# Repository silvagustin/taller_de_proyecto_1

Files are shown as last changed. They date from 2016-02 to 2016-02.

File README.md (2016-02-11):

# Proyecto: Control para una matriz de LEDs

### Palabras clave:
- EDU CIAA-NXP, CIAA, poncho, shield, matriz de leds 8x8, LCD 1602,LCD 16x02, teclado matricial.

### Interfaces:
- LCD 16x02
- Teclado Matricial 4 filas 3 columnas

### Grupo 5, integrantes:
- Buján Ariel,   157/0
- Delgado David, 139/8
- Silva Agustín, 63/5

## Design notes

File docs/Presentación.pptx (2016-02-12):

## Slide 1

Control de una matriz de LEDs de N x N con la EDU-CIAA

157/0 – Buján, Ariel
139/8 – Delgado, David
63/5 – Silva, Agustín

## Introducción

- Se diseñó e implementó un poncho para la placa controladora EDU-CIAA. Dicho poncho sirve para controlar una matriz de leds de 8x8, y cuenta con una interfaz de entrada/salida para comunicarse con el usuario.

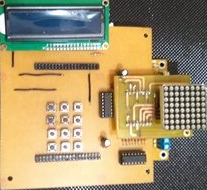
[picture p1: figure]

## Materiales

- 1 Matriz de Leds de 8x8
- 1 Display LCD 16x02
- 1 Demultiplexor CMOS 74HC238 DIP-16
- 1 Demultiplexor CMOS 74HC138 DIP-16
- 2 Tiras de 20 pines macho dobles
- 2 Tiras de 8 pines hembras
- 1 Tira de 16 pines hembras
- 12 Pulsadores touch de 6 mm
- 2 Capacitores cerámicos de 100nF
- 2 Capacitores electrolíticos de 22uF
- 9 Resistencias de 220 ohms
- 1 Preset de 10k ohm
- 1 Placa pcb de cobre

## Funcionamiento del sistema

- El sistema total del poncho puede dividirse en tres grandes subsistemas, que se intercomunican entre sí:

- Control de la Matriz de 8x8
- Display LCD
- Teclado Matricial

## Control de la Matriz de 8x8

- El control de la matriz de leds se realiza mediante dos demultiplexores, uno normal, el cual devuelve una sola salida activa por combinación en las entradas, y uno invertido, que devuelve todas las salidas excepto una encendidas en la salida por combinación en la entrada.
- Los demultiplexores se controlan con ocho puertos GPIO configurados como salidas.
- Tres puertos para controlar la combinación en las entradas del demultiplexor y el cuarto para habilitar o deshabilitar el Enable 1.
- Los pines de las matrices comerciales pueden variar entre los diferentes modelos. Este poncho está pensado para poder ser utilizado con cualquiera de estos modelos, para esto se le añade un sobre-poncho el cual, la única función que cumple es reordenar los pines de forma que un demultiplexor controle las filas y el otro controle las columnas.

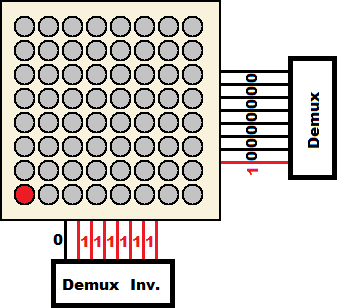
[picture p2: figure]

## Display LCD

- Se utilizaron los pines asignados en el diseño de la EDU-CIAA para controlar el Display, pero, debido a que aún no existe un driver destinado a controlar este componente, se implementó por medio del control de los GPIO, enviando un paquete de bits en paralelo y luego un bit por el puerto RS para indicar si se trataba de un dato o una instrucción.

## Teclado Matricial

- Una vez más se utilizaron los pines asignados por el diseño de la EDU-CIAA pero se implementaron las funciones de control por medio de los GPIO.
- 4 GPIOs definidos como salidas ( para las filas), que sucesivamente cambian de estado de forma que siempre haya uno con valor 0(cero) y el resto con valor 1(uno).
- 3 GPIOs definidos como entradas con PULL-UP (para las columnas).
- De esta forma se puede identificar que pulsador se presionó, conociendo en qué entrada llegó un 0(cero), y que salida tiene ese valor asignado.

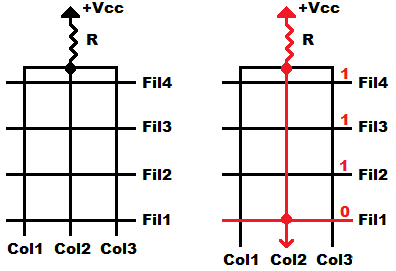
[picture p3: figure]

## Teclado Matricial

- Nota: Cabe destacar que el PULL-UP es una medida de seguridad, ya que sin este, la conexión realizada entre Vcc y GND (el GPIO puesto en 0) resultara en un cortocircuito, al existir una resistencia (programada al definir el GPIO) se limita la corriente que ingresa por los puertos de las columnas, y de este modo no se daña la EDU-CIAA.

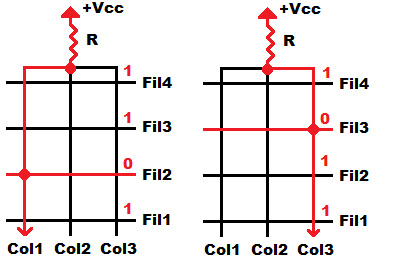
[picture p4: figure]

## Menú de la interfaz

- Menú principal: Luego de encender la placa, aparecerá un mensaje de bienvenida durante algunos segundos, seguido del menú principal que permitirá al usuario moverse entre las funciones básicas del sistema.

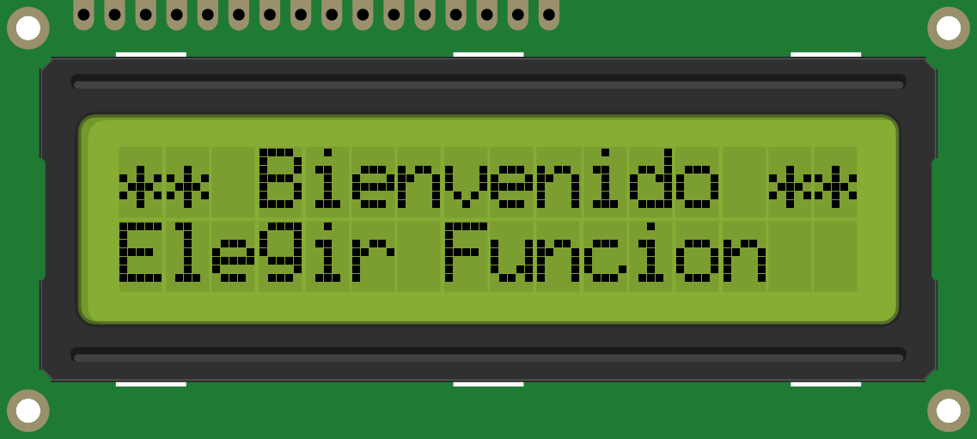
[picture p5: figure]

## Menú Principal

Para moverse por las funciones se utilizan los botones 4 y 6 (las flechitas), al llegar a la ultima función el circulo vuelve a empezar. Para seleccionar una función debe presionarse la tecla OK.
Las funciones son:
  - Escribir Texto
  - Enviar Texto
  - Velocidad Matriz

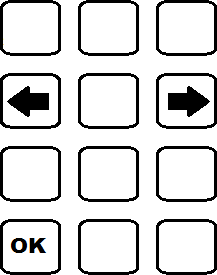
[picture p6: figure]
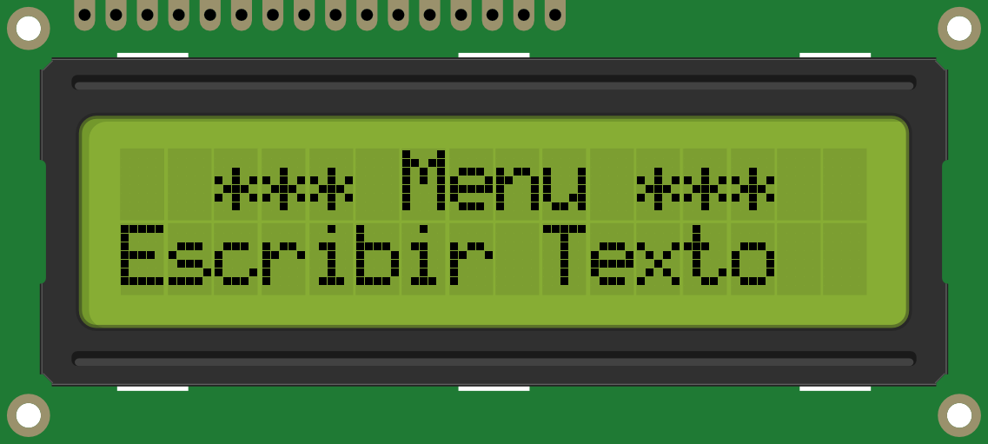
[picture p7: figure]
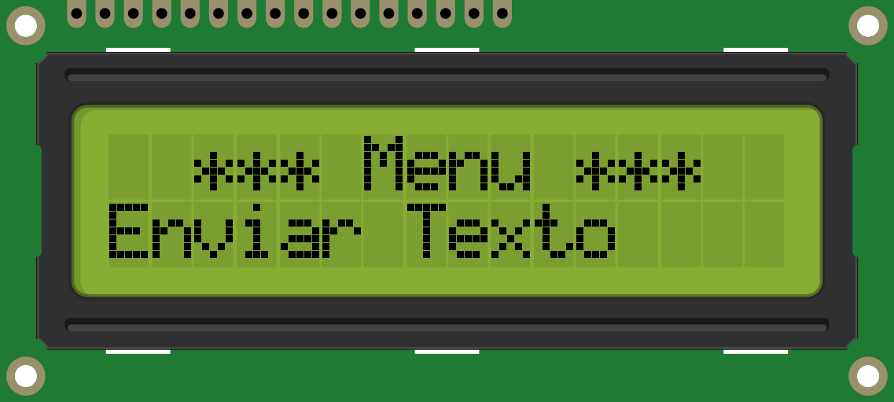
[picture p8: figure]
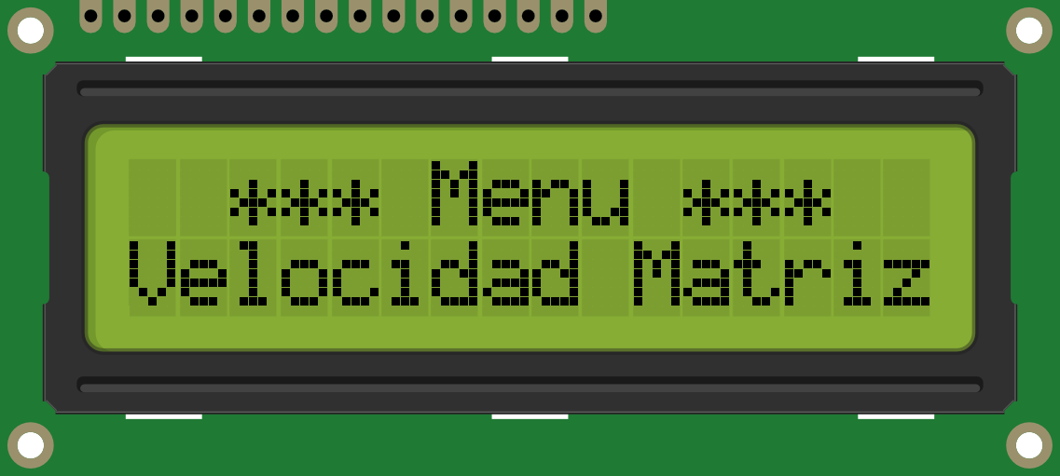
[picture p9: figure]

## Escribir texto

- Permite escribir un texto para ser enviado y mostrado en la matriz de leds, el control es bastante intuitivo. La distribución de teclas está dada de una forma similar a los celulares de la década del 90.

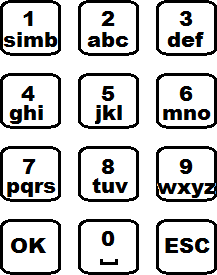
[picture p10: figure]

## Escribir texto – Maquina de Estados

- Modo Escritura: Luego de seleccionar un carácter se debe confirmar el mismo con la tecla OK.
- Modo Borrado: Si se desea borrar un carácter o más, se debe presionar dos veces ESC, de esta forma se ingresa al modo borrado, para continuar borrando se debe volver a presionar ESC. Para volver al modo escritura, se debe presionar OK nuevamente.
- Modo Salida: Para volver al menú principal se debe presionar una vez la tecla ESC y confirmar con OK.

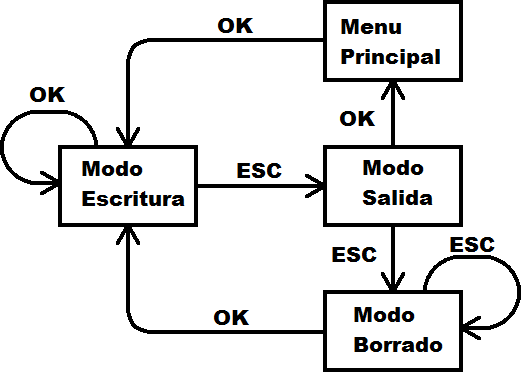
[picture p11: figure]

## De modo escritura a modo borrado pasando por modo salida

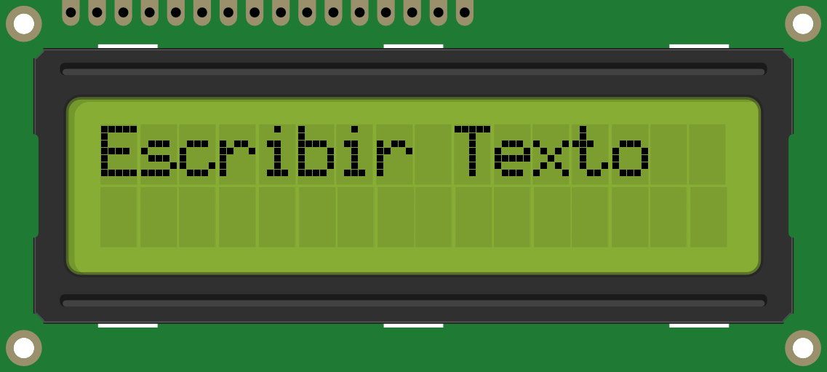
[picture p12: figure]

…

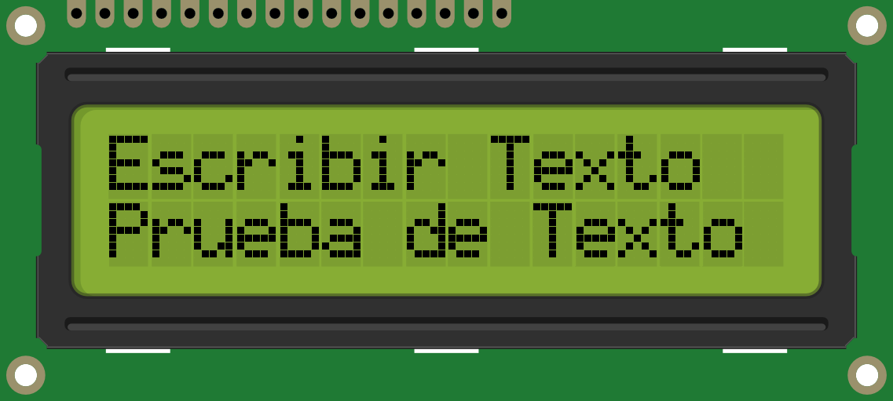
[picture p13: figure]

ESC

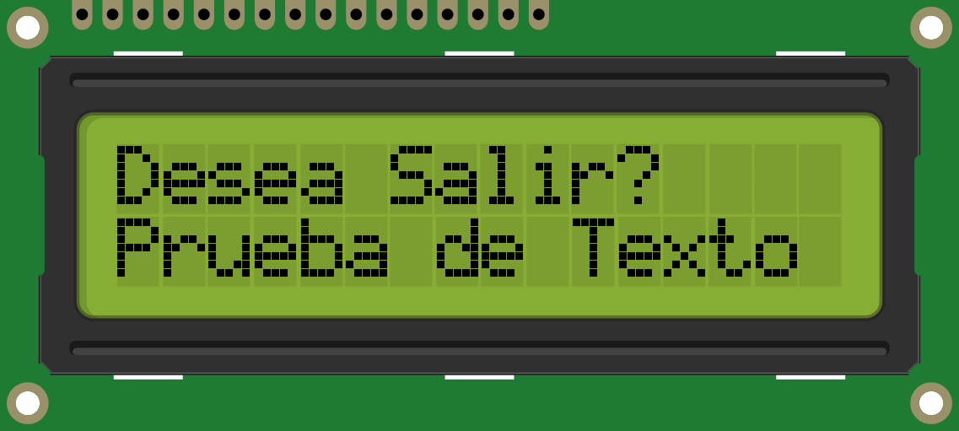
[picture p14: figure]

ESC

ESC

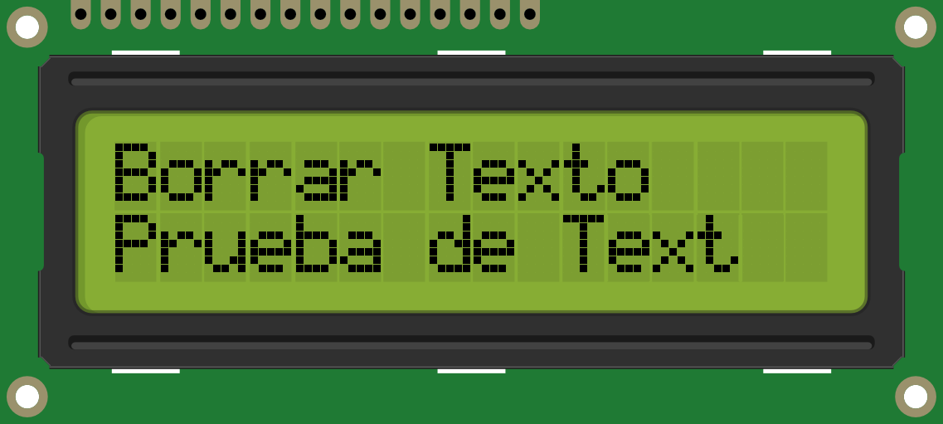
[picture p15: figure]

ESC

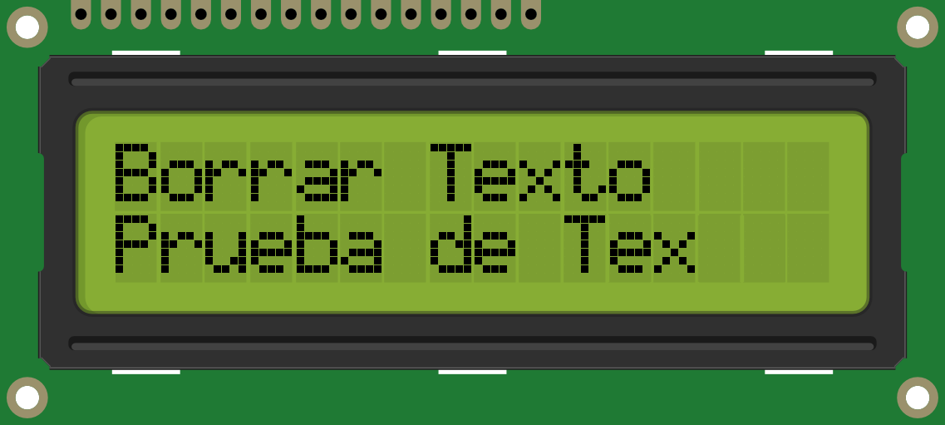
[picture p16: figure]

## De modo escritura a modo salida

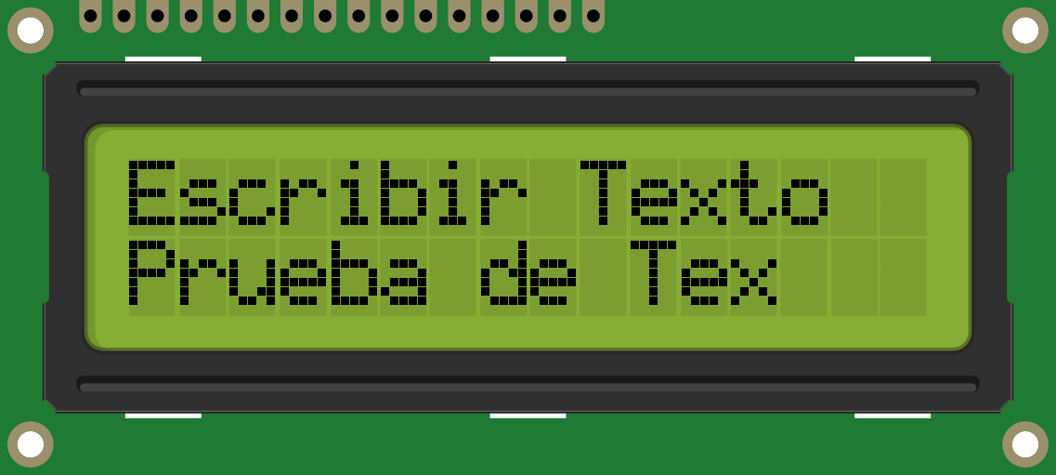
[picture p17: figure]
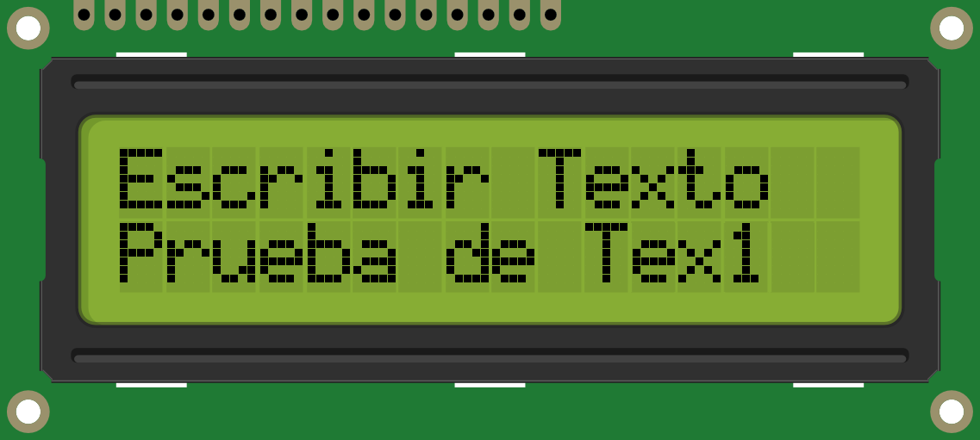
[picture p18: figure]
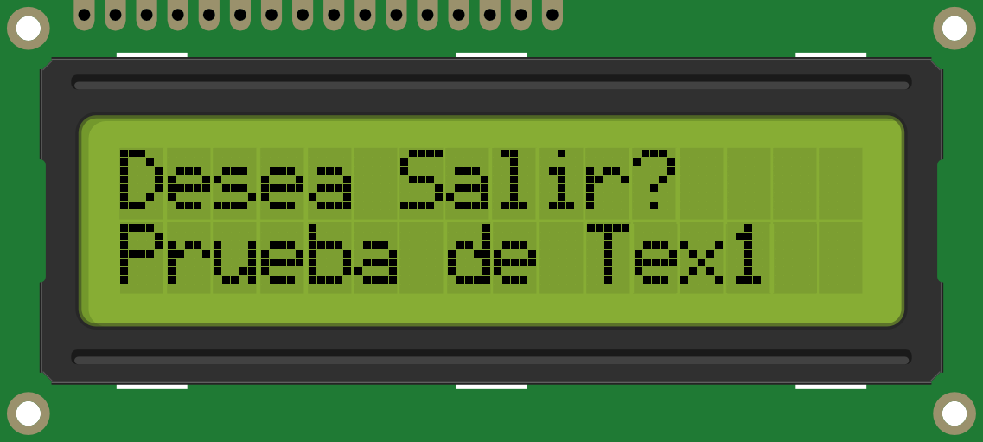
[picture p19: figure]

OK

…

ESC

## Enviar Texto

- Luego de escribir el texto se debe enviar a la matriz para poder visualizarlo, En esta función la única acción que puede tomar el usuario es salir de la misma, presionando el botón OK o ESC.

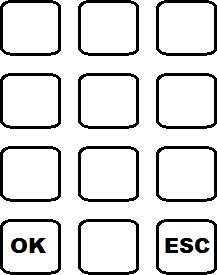
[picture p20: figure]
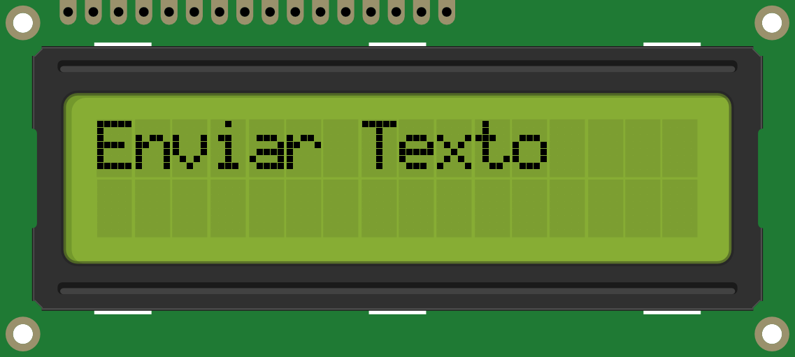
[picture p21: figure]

## Velocidad Matriz

- Este menú permite configurar la velocidad de desplazamiento de la matriz, se aumenta o disminuye la velocidad con los pulsadores 6 y 4 respectivamente, y se sale de la función con los pulsadores OK o ESC.

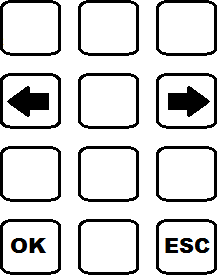
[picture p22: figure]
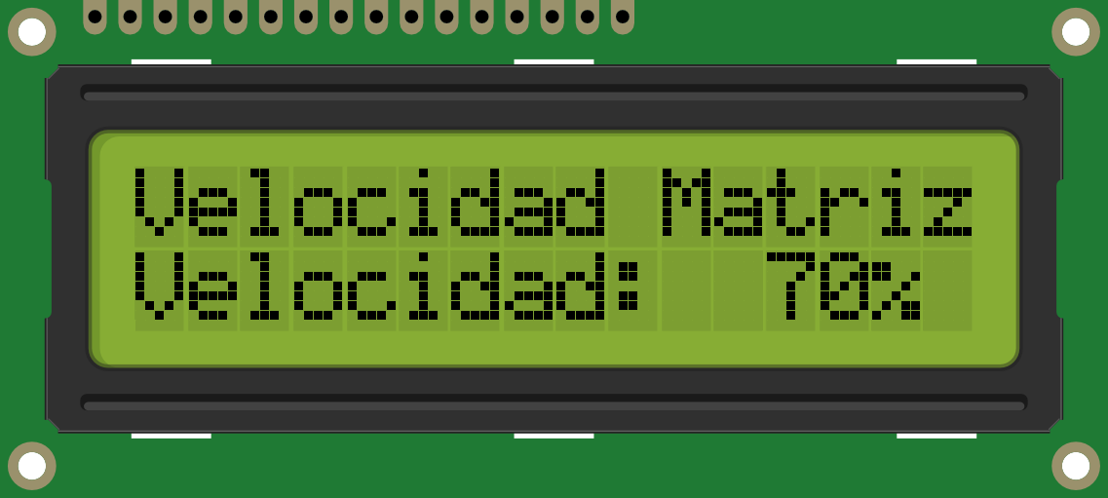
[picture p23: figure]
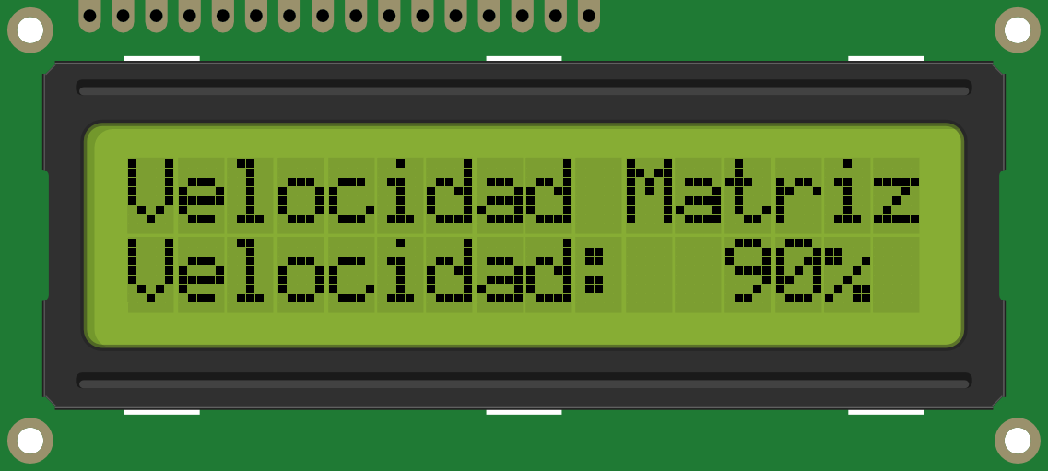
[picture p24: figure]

->

## Muchas Gracias

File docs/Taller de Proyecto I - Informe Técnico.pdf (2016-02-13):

# Taller de Proyecto I

## Informe Técnico

Grupo:5
Proyecto:Control para una matriz de leds

Integrantes del grupo:
Buján Ariel, 157/0
Delgado David, 139/8
Silva Agustín, 063/5

## ÍNDICE

Resumen | Página 2
Palabras Clave | Página 2
Introducción | Página 2
Desarrollo | Página 2
Propuesta | Página 4
Análisis entre lo propuesto y lo realizado | Página 4
Esquema gráfico | Página 5
Materiales y presupuesto | Página 6
Funcionamiento del sistema | Página 7
Matriz de 8x8 | Página 7
Display LCD | Página 8
Teclado Matricial | Página 8
Menú de la interfaz | Página 9
Menú principal | Página 9
Escribir texto | Página 9
Enviar Texto | Página 10
Velocidad Matriz | Página 13
Diagramas de diseño | Página 14
Ensamblado de la placa PCB | Página 18
Explicación básica del código | Página 18
Programa Principal | Página 18
Menú Principal | Página 18
Elegir función | Página 18
Escribir Texto | Página 19

Escribir LCD | Página 19
Enviar Texto | Página 19
Envía texto | Página 19
Siguiente letra | Página 20
Cargar letra | Página 20
Velocidad Desplazamiento Matriz | Página 20
Explicación técnica del código | Página 20
Control de las GPIOs | Página 20
Inicializar GPIO | Página 20
Control de los demultiplexores | Página 20
Datos LCD | Página 20
Datos Matriz | Página 21
Control de teclado | Página 21
Entradas Teclado | Página 21
Salidas Teclado | Página 21
Leer Teclado | Página 21
Tareas Realizadas | Página 22
Conclusión | Página 22
Apéndice | Página 23
Bibliografía | Página 26

## Resumen

En este informe se explicarán de forma detallada las tareas realizadas para el desarrollo de un poncho para la EDU-CIAA-NXP en un proyecto de la materia “Taller de Proyecto 1” del cuarto año de la carrera de Ingeniería en Computación de la Facultad de Ingeniería de la Universidad Nacional de La Plata. Este sistema controla una matriz de leds de 8x8 y cuenta con una interfaz de entrada/salida para que el usuario pueda escribir texto y enviarlo, para ser mostrado en la matriz.

## Palabras Clave

EDU CIAA-NXP, CIAA, poncho, shield, matriz de leds 8x8, LCD 1602, teclado matricial.

## Introducción

La EDU-CIAA-NXP tiene dos características distintivas. Es Industrial, ya que su diseño es lo suficientemente robusto para soportar las exigencias que demandan los productos y procesos industriales; y es abierta, es decir, que la información sobre su diseño de hardware, firmware, software, etc. es de libre acceso y cualquiera la puede utilizar.
Este año en la materia Taller de Proyecto 1 de Ingeniería en Computación se propuso realizar un proyecto donde se diseñara y fabricara un poncho para la EDU-CIAA-NXP. El objetivo de este informe es realizar una descripción detallada del diseño del hardware y software, de los procedimientos realizados y del funcionamiento del sistema desarrollado e implementado.

## Desarrollo

El poncho encastrado en la EDU CIAA-NXP trabaja como intermediario entre los sensores (los pulsadores) y actuadores (la matriz de leds, el display LCD) que tiene el sistema,

Durante el diseño del sistema, se tuvieron en cuenta algunas características importantes:

- Utilizar un radio mínimo 0.7 mm en los agujeros pasantes, y de 2 mm en las pistas para evitar que se levanten las mismas.
- Utilizar pistas de 1 mm de ancho para evitar que se levanten y/o corten al atacar la placa con ácido.
- Evitar dejar pistas con esquinas a 90º, ya que estas acumulan cargas, y producen ruido.
- Utilizar capacitores conectados entre VCC y GND cerca de los circuitos integrados para reducir el potencial ruido en el circuito.
- Mantener las pistas de la placa separadas por cierta distancia prudencial, para evitar ruido, y posibles cortocircuitos.
- Utilizar un sobreponcho para conectar la matriz, ya que las matrices de leds comerciales tienen distintas distribuciones de pines, dependiendo del modelo.

### Propuesta

Diseñar e implementar un poncho adaptador que sirva para comunicar la placa EDU-CIAA con una matriz de LEDs de NxN, pudiéndose mostrar en la misma texto en forma de caracteres, o símbolos definidos por software.
Además de implementar una interfaz con el exterior por medio de un display y un teclado.

### Análisis entre lo propuesto y lo realizado

Se lograron cumplir con todas las metas según la propuesta planteada, se realizó un sistema que controla una matriz de leds de 8x8 y posee una interfaz con el exterior por medio de un teclado matricial, y un display LCD de 16x02.

### Esquema gráfico

La siguiente imagen tiene la funcion de ilustrar al lector en cuanto a la distribución de componentes básicos y el aspecto del poncho una vez terminado:


Figura 1.1:Esquema ilustrativo del poncho.

### Materiales y presupuesto

Tabla 1.1:Componentes utilizados y sus precios estimados al mes de noviembre del 2015

Elemento / Componente | Cantida d | Precio por unidad
Placa de desarrollo EDU-CIAA-NXP | 1 | $500
Display LCD 16x02 | 1 | $100
Matriz de Leds de 8x8 | 1 | $50
Demultiplexor CMOS 74HC238 DIP-16 | 1 | $20
Demultiplexor CMOS 74HC138 DIP-16 | 1 | $20
Capacitores cerámicos de 100nF | 2 | Estimado entre todo: $35
Capacitores electrolíticos de 22uF | 2
Resistencias de 220 ohms | 9
Preset de 10k ohm | 1
Pulsadores touch de 6 mm | 12
Tiras de 20 pines macho dobles | 2 | $12
Tira de 16 pines hembras | 1 | 5
Tiras de 8 pines hembras | 4 | 2.5
Tiras de 8 pines macho | 2 | 2.5
Placa PCB de cobre 20x20 | 1 | $40
Placa PCB doble faz de cobre 10x10 | 1 | $15
Total | | $824

### Funcionamiento del sistema

El sistema total del poncho puede dividirse en tres grandes subsistemas, que se intercomunican entre sí:

Matriz de 8x8

El control de la matriz de leds se realiza mediante dos demultiplexores, uno normal, el cual devuelve una sola salida activa por combinación en las entradas, y uno invertido, que devuelve todas las salidas excepto una encendidas en la salida por combinación en la entrada:


Figura 2.1:Funcionamiento de la Matriz de leds con demultiplexores

Los demultiplexores se controlan con ocho puertos GPIO (cuatro para cada uno) configurados como salidas. A partir de ellos se mapea el led encendido con el valor en la salida de los GPIOs.

Los primeros tres puertos son utilizados para controlar la combinación en las entradas del demultiplexor correspondiente, y el cuarto es utilizado para habilitar o deshabilitar el Enable, y de esta forma poder encender o apagar la matriz en su totalidad.
Cabe destacar que los pines de las matrices comerciales pueden variar entre los diferentes modelos. Este poncho está pensado para poder ser utilizado con cualquiera de estos modelos, para esto se le añade un sobreponcho el cual, la única función que cumple es reordenar los pines de forma que un demultiplexor controle las filas y el otro controle las columnas (El diseño utilizado para este sobreponcho queda a modo de ejemplo en el anexo).

Display LCD

Se utilizaron los pines asignados en el diseño de la EDU-CIAA para controlar el Display, pero, debido a que aún no existe un driver destinado a controlar este componente, se implementó por medio del control de los GPIO, enviando un paquete de bits en paralelo y luego un bit por el puerto RS para indicar si se trataba de un dato o una instrucción. De esta forma, se fueron definiendo funciones tales como:

- Inicializar Display
- Imprimir un carácter
- Imprimir 16 caracteres
- Posicionarse en una linea especifica

Una vez definidas todas esas funciones, únicamente restaba implementar un menú para hacer que la interfaz sea amigable con el usuario.

Teclado Matricial

Una vez más se utilizaron los pines asignados por el diseño de la EDU-CIAA pero se implementaron las funciones de control por medio de los GPIO. El funcionamiento del teclado son básicamente:

- 4 GPIOs definidos como salidas (los 4 puertos destinados a las filas), que sucesivamente cambian de estado de forma que siempre haya uno con valor 0(cero) y el resto con valor 1(uno).
- 3 GPIOs definidos como entradas con PULL-UP (los 3 puertos destinados a columnas).
De esta forma se puede identificar que pulsador se presionó, conociendo en qué entrada llegó un 0(cero), y que salida tiene ese valor asignado.


Figura 2.2:Funcionamiento del teclado matricial (pulsador 21 presionado)


Figura 2.3:Funcionamiento del teclado matricial (Imagen A:pulsador 12 presionado; Imagen B:pulsador 33 presionado)

Nota: Cabe destacar que el PULL-UP es una medida de seguridad, ya que sin este, la conexión realizada entre Vcc y GND (el GPIO puesto en 0) resultara en un cortocircuito, al existir una resistencia (programada al definir el GPIO) se limita la corriente que ingresa por los puertos de las columnas, y de este modo no se daña la EDU-CIAA.

Menú de la interfaz

Menú principal

Luego de encender la placa, aparecerá un mensaje de bienvenida, seguida del menú principal que permitirá al usuario moverse por las funciones con las flechitas, y seleccionar una con la tecla OK.


Figura 2.4:Distribución del teclado en el menú principal


Figura 2.5:Máquina de Estados del menú principal

Escribir texto

Permite escribir un texto para ser enviado y mostrado en la matriz de leds, el control es bastante intuitivo. La distribución de teclas está dada de una forma similar a los celulares de la década del 90.

- Modo Escritura: Luego de seleccionar un carácter se debe confirmar el mismo con la tecla OK.
- Modo Borrado: Si se desea borrar un carácter o más, se debe presionar dos veces ESC, de esta forma se ingresa al modo borrado, para continuar borrando se debe volver a presionar ESC. Para volver al modo escritura, se debe presionar OK nuevamente.
- Modo Salida: Para volver al menú principal se debe presionar una vez la tecla ESC y confirmar con OK.


Figura 2.6:Distribución del teclado en la función escribir


Figura 2.7:Máquina de Estados de la función escribir

Enviar Texto

Luego de escribir el texto se debe enviar a la matriz para poder visualizarlo, En esta función la única acción que puede tomar el usuario es salir de la misma, presionando el botón OK o ESC.


Figura 2.8:Distribución del teclado en la función enviar texto


Figura 2.9:Máquina de Estados de la función Enviar Texto

Velocidad Matriz

Este menú permite configurar la velocidad de desplazamiento de la matriz, se aumenta o disminuye la velocidad con los pulsadores 6 y 4 respectivamente, y se sale de la función con los pulsadores OK o ESC.


Figura 2.10:Distribución del teclado en la función velocidad matriz

### Diagramas de diseño

Para definir el diagrama esquemático del circuito y el diagrama PCB (que muestra las conecciones de las pistas de cobre sobre la placa) se deben interpretar los requerimientos funcionales (comportamientos del sistema), y los requerimientos no funcionales (limitaciones del sistema). A partir de ello se eligen qué componentes utilizar y como interconectarlos entre sí. Para esto se utilizó el software libre Kicad, que cuenta con las herramientas necesarias para diseñar estos diagramas.
Para realizar el esquemático se agregó la librería del circuito integrado 74HC238 (el demultiplexor) y del 74HC138 (el demultiplexor invertido) que pueden encontrarse en internet.

Se conectaron las salidas digitales de propósito general (GPIO) de la CIAA a las entradas y el pin de enable de los demultiplexores. También se conectan los pines correspondientes al LCD y se hizo lo propio con el teclado matricial.


Figura 3.1:Diagrama esquemático del sobreponcho

Nota: el diagrama esquemático mostrado en la figura 4.6 es exclusivo para una matriz de leds de 8x8 modelo M12088 A/B, para otros modelos sería necesario diseñar otro sobreponcho.


Figura 3.2: Diagrama esquemático del poncho

Tabla 3.1:Conexionado poncho-EDU CIAA

Pin | Conectado a | Pin | Conectado a
SPI_MISO | Pin de enable demux 1 | T_FIL0 | Pines de Filas como entradas
GPIO1 | Entrada 1 demux 1 | T_FIL1
GPIO3 | Entrada 2 demux 1 | T_FIL2
GPIO5 | Entrada 3 demux 1 | T_FIL3
GPIO4 | Pin de enable demux 2 | LCD_EN | Pin de Enable del LCD
GPIO6 | Entrada 1 demux 2 | LCD_RS | Pin de Datos/Instrucciones
GPIO7 | Entrada 2 demux 2 | LCD1 | Pines de datos
GPIO8 | Entrada 3 demux 2 | LCD2
T_COL0 | Pines de Columnas como salidas | LCD3
T_COL1 | | LCD4

T_COL2

Una vez diseñado el esquemático se deben asignar los footprints (que son básicamente las formas y tamaños de los componentes utilizados en el diagrama PCB). Se utilizaron pistas de 1 mm de ancho, agujeros pasantes de radio mínimo 0.7 mm y pistas de radio mínimo 2 mm.


Figura 3.3: Diagrama PCB del poncho

Figura 3.4: Diagrama PCB del sobreponcho

### Ensamblado de la placa PCB

Inicialmente se cortó a medida la placa de cobre, luego se limpió bien la superficie con virulana y detergente. Se imprimió el diagrama PCB con una impresora láser, en un papel fotográfico de 90 gramos. Se transfirió el diseño a la placa con una plancha, mientras aún estaba caliente, se la sumergió en agua fría, para así poder despegar el papel. Una vez removidos los restos del papel se procedió a sumergir la placa en ácido cúprico que “comerá” el cobre, exceptuando las zonas que estén cubiertas con toner. Se procedió a perforar la placa y a limpiarla para remover los restos de tóner. Luego se la pinto con una capa de resina para protegerla y evitar que se opaquen las pistas y por último se soldaron los componentes.
Este proceso se repitió para él sobreponcho, aunque este requirió mayor cuidado, ya que al ser una placa de doble faz es necesario que los agujeros pasantes coincidan.

### Explicación básica del código

Programa Principal
Se inicializan todas las variables, el display LCD, y la matriz de leds apagada. Luego se imprime en el display un mensaje de bienvenida que dura unos segundos. Por último se accede al lazo principal que corresponde al menú principal, de esta forma se invoca a “Elegir función” que devolverá un número correspondiente a la opción escogida. Este número se evaluará en un switch que invocara a la función correspondiente.

Menú Principal

Elegir función
Se itera leyendo desde el teclado, a la espera de que se presionen las teclas correspondientes a las flechas laterales (pulsador 4 o 6), imprimiendo el nombre de la función siguiente o anterior según corresponda. O la tecla Ok (pulsador 10) que simboliza que se selecciono una función y retorna el número correspondiente.

Escribir Texto

Escribir LCD
Es un lazo que detecta que tecla se presiono y actúa en base a ello, si se presiona:
- Cualquier tecla excepto la 10 (OK) o la 12 (ESC), se lee el caracter correspondiente y se lo imprime en el display, si la siguiente tecla presionada es:
- OK, se agrega el carácter a la palabra, y se avanza una posición en el display.
- La misma recién presionada, se incrementa un contador para avanzar al siguiente carácter, y se lo imprime en el display sin avanzar de posición.
- ESC se pasa al modo Salida.
- Distinta de la recién presionada, siempre se reinicializa el contador (también en OK y ESC).
- OK:
- Y no habia ningun caracter seleccionado, no pasa nada.
- Y estaba en modo Salida, se regresa al Menú Principal.
- Y estaba en modo Borrado, se pasa a modo Escritura.
- ESC:
- Y estaba en modo borrado, borra el siguiente carácter.
- Y estaba en modo Salida, pasa a modo Borrado

Enviar Texto

Envía texto
Esta función lee los datos de una matriz que funciona como un buffer y cambia el estado de los GPIOs correspondientes a los demultiplexores, para mostrar la información en la matriz de leds. Cuando termino de leer todos los datos en la matriz buffer, llama a la función “siguiente letra” para que cargue mas. En caso de llegar al final del texto, simplemente se repite la misma desde el inicio.

Siguiente letra
Es la función que interpreta los caracteres del texto y se los envía como parámetros en la invocación de “cargar letra”.

Cargar letra
Se encarga de recibir una letra, y cargar la matriz buffer con los datos asociados para esa letra en la librería letrasMatriz.h. La funcion también recibe una posición, que indica en qué posición de la matriz buffer se deben guardar los datos.

Velocidad Desplazamiento Matriz
Esta función lee del teclado esperando que se presionen las teclas 4 o 6 (las flechas horizontales) y modifica una variable de delay en base a la tecla presionada, de esta forma se espera más o menos al hacer el desplazamiento, y se modifica la velocidad.

### Explicación técnica del código

Control de las GPIOs

Inicializar GPIO

Utilizando funciones definidas en el firmware disponible de la EDU-CIAA, configuramos la función a utilizar de cada pin (ya que cada uno posee diferentes funciones que varían según su implementación) y si es utilizado como entrada o salida. En la tabla 3.1 que se encuentra antes definida, se pueden observar los pines utilizados y que función cumplen en el poncho.

Control de los demultiplexores

Datos LCD

Esta función recibe como parametro un valor y lo envía comparando bit a bit, hacia los pines conectados al display LCD, en el siguiente formato: Los primeros 4 bits son de

datos, el 5

to bit es que determina si es dato o instrucción, y el 6

to y último bit es el Enable para que la pantalla lea lo último que le fue enviado,

Datos Matriz

Esta función al igual que la anterior, recibe como parametro un valor y lo envía comparando bit a bit, hacia los demultiplexores conectados a la matriz. Siguiendo el siguiente formato: 3 bits de datos y 1 para el Enable, así tanto para el demultiplexor conectado a las filas como para el demultiplexor conectado a las columnas.

Control de teclado

Entradas Teclado

Esta función simplemente lee los valores de los pines conectados entradas y los retorna como un valor de tipo entero el cual consta del siguiente formato: El 1

er bit
corresponde a la primera columna, el 2

do corresponde a la segunda columna y el 3

er bit
corresponde a la tercer columna.

Salidas Teclado

Esta función recibe como parametro un valor y lo envía hacia los pines conectados a las filas del teclado, cambiando los estados de las 4 filas, con los 4 bits enviados como parámetro.

Leer Teclado

Esta función realiza un polling de las entradas del teclado a medida que va activando las salidas. Primero habilita la primer fila del teclado y lee los valores de las columnas, para saber que tecla fue apretada. Luego repite el procedimiento con las otras 2 columnas. Este procedimiento fue explicado en una sección anterior.

### Tareas Realizadas

En la Tabla 3.1 se especifican las tareas que realizo cada integrante, las mismas fueron asignadas de acuerdo a la afinidad de cada uno con los conocimientos de electrónica o de programación.

Tabla 4.1:Componentes utilizados y sus precios estimados al mes de noviembre del 2015

Tarea | Realizada por
Diseño del diagrama esquemático | Buján, Delgado, Silva
Diseño del diagrama PCB | Buján
Diseño del sobreponcho | Delgado
Prueba del circuito en el protoboard | Buján, Delgado, Silva
PCB | Buján, Delgado
PCB del sobreponcho | Buján, Delgado
Software de GPIO | Buján, Delgado
Software del display LCD | Silva
Software de control de demultiplexores e impresión de texto en Matriz | Buján, Delgado
Software de teclado y menús | Buján
Informe Presentación Power Point | Buján, Delgado, Silva

## Conclusión

En este proyecto se desarrolló un sistema de control sobre la placa de desarrollo EDU-CIAA-NXP, la cual tiene poco tiempo en el mercado, y aún existe muy poca información drivers y firmwares desarrollados, por lo tanto la investigación sobre la misma en ocasiones es compleja, sin embargo también es más fructífera y gratificante al obtener resultados.
Consideramos que esta experiencia fue muy enriquecedora, en muchos aspectos competentes a nuestra carrera, creemos además que fue interesante desarrollar un sistema prácticamente desde cero, y fue muy satisfactorio ver que funcione como se esperaba.

## Apéndice

En esta sección se mostrarán hojas de datos y detalles tomados en cuenta en el diseño:


Figura 5.1:Conexionado interno del Demultiplexor 74HC238


Figura 5.2:Conexionado interno del Demultiplexor invertido 74HC138

Figura 5.3: Tabla de verdad del Demultiplexor 74HC238


Figura 5.4:Tabla de verdad del Demultiplexor invertido 74HC138

Figura 5.5: Conexionado interno de la matriz de LEDs

## Bibliografía

Hoja de datos del demultiplexor CMOS 74HC138: http://www.nxp.com/documents/data_sheet/74HC_HCT138.pdf

Hoja de datos del demultiplexor CMOS 74HC238: http://www.nxp.com/documents/data_sheet/74HC_HCT238.pdf

Hoja de datos de los pulsadores de 6 mm: https://www.hdk.co.jp/pdf/eng/e291702.pdf

Hoja de datos de la matriz de leds: http://pdf1.alldatasheet.com/datasheetpdf/view/574249/LIGHTKEY/LM12088AB.html

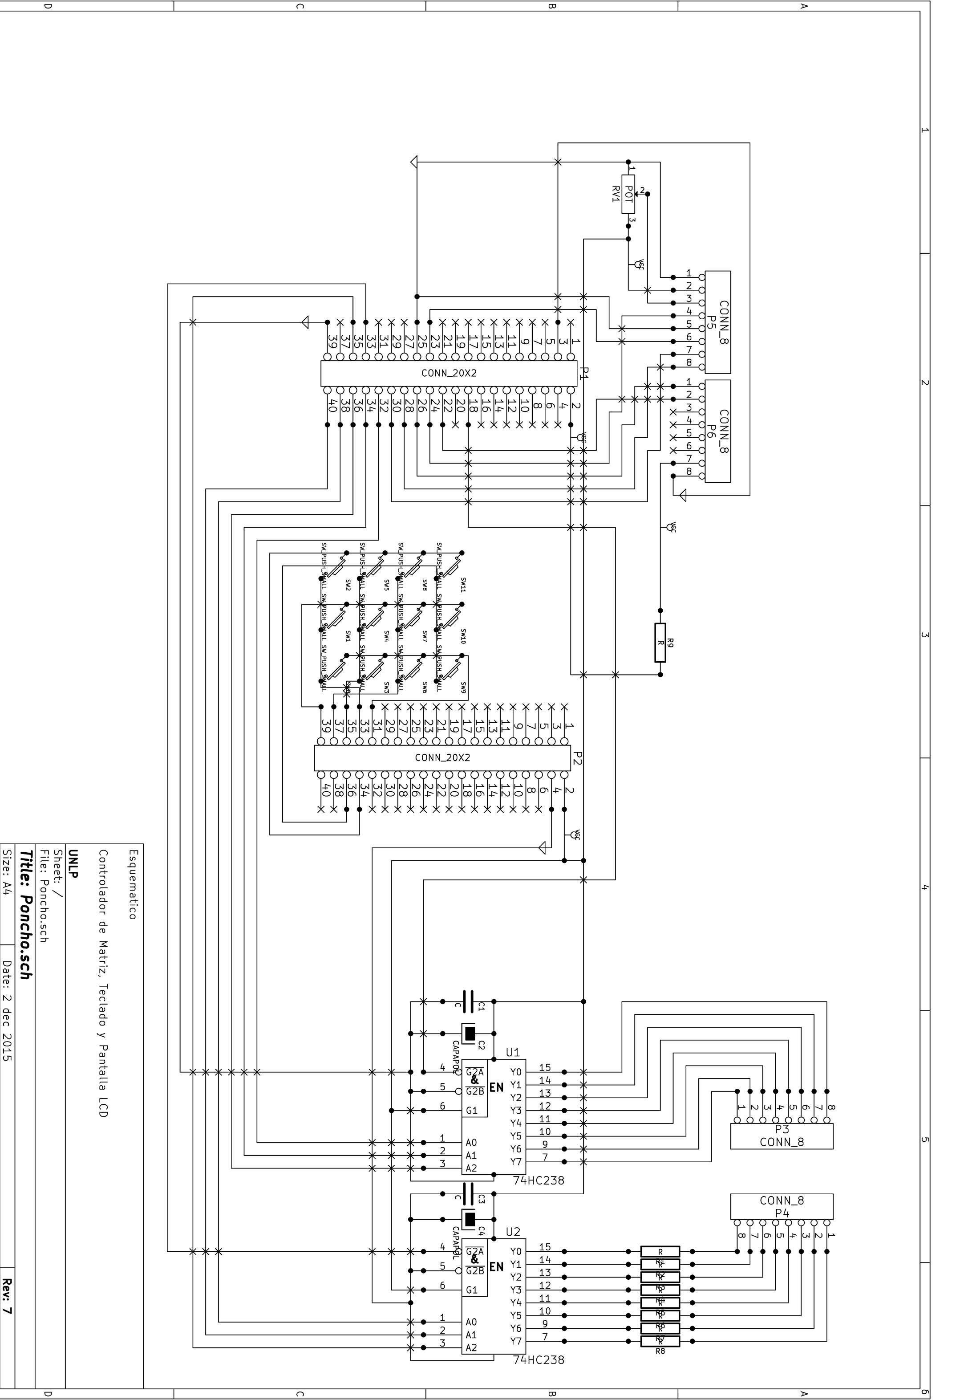
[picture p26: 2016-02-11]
docs/images/Esquematicos/Esquematico.png

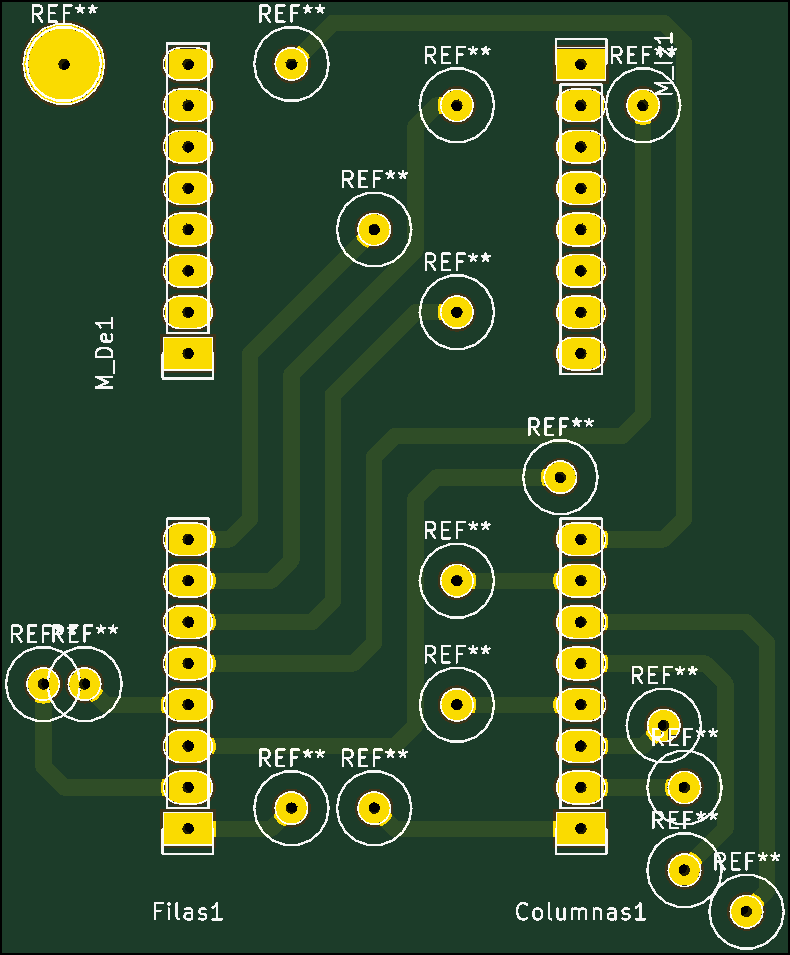
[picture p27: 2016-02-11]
docs/images/PCB/SubPoncho Superior.png

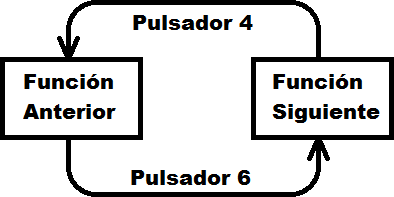
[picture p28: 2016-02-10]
docs/images/Maquinas de Estado/MaquinaEstado - Menu Principal.png

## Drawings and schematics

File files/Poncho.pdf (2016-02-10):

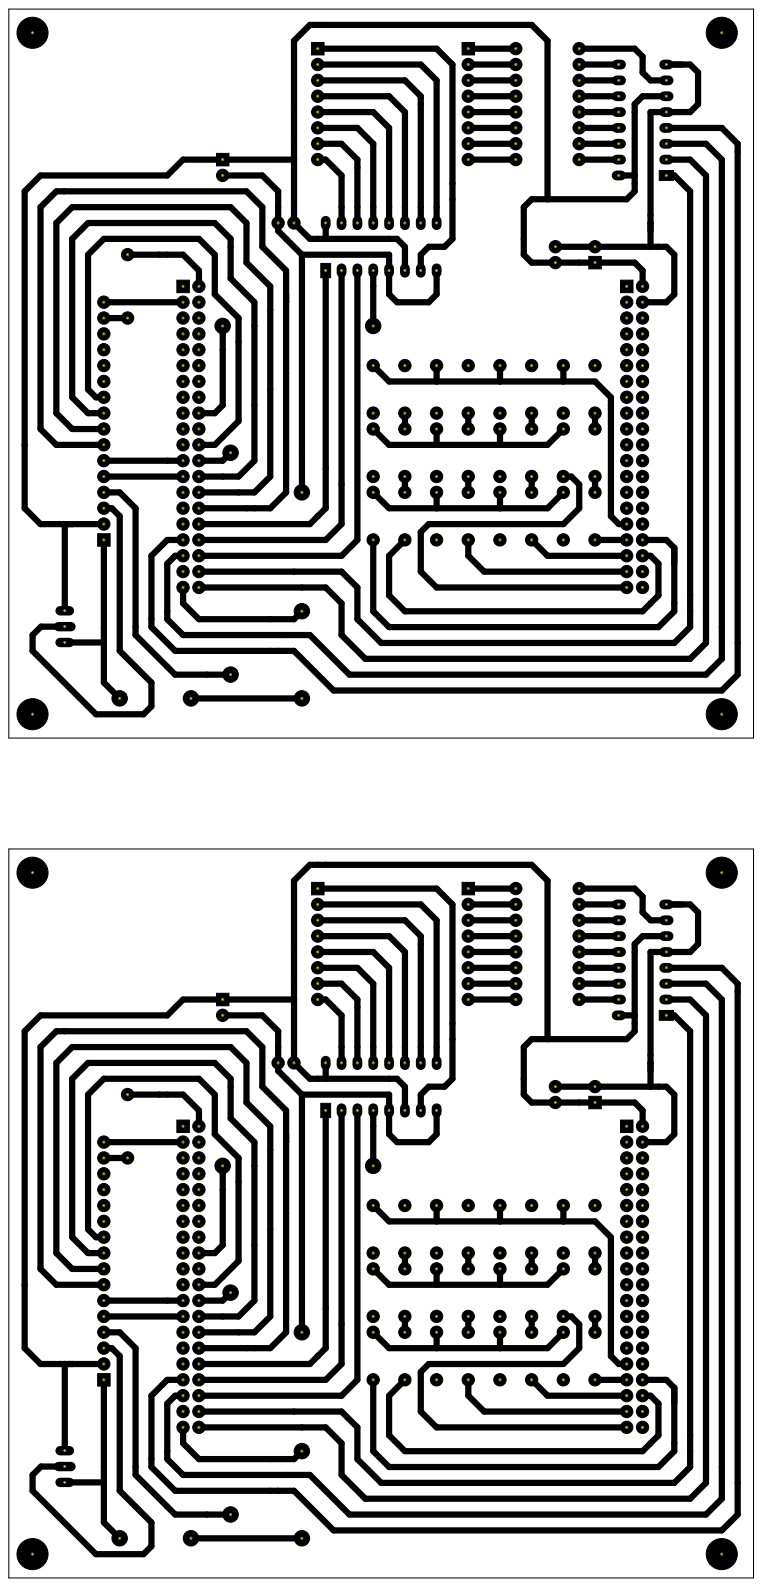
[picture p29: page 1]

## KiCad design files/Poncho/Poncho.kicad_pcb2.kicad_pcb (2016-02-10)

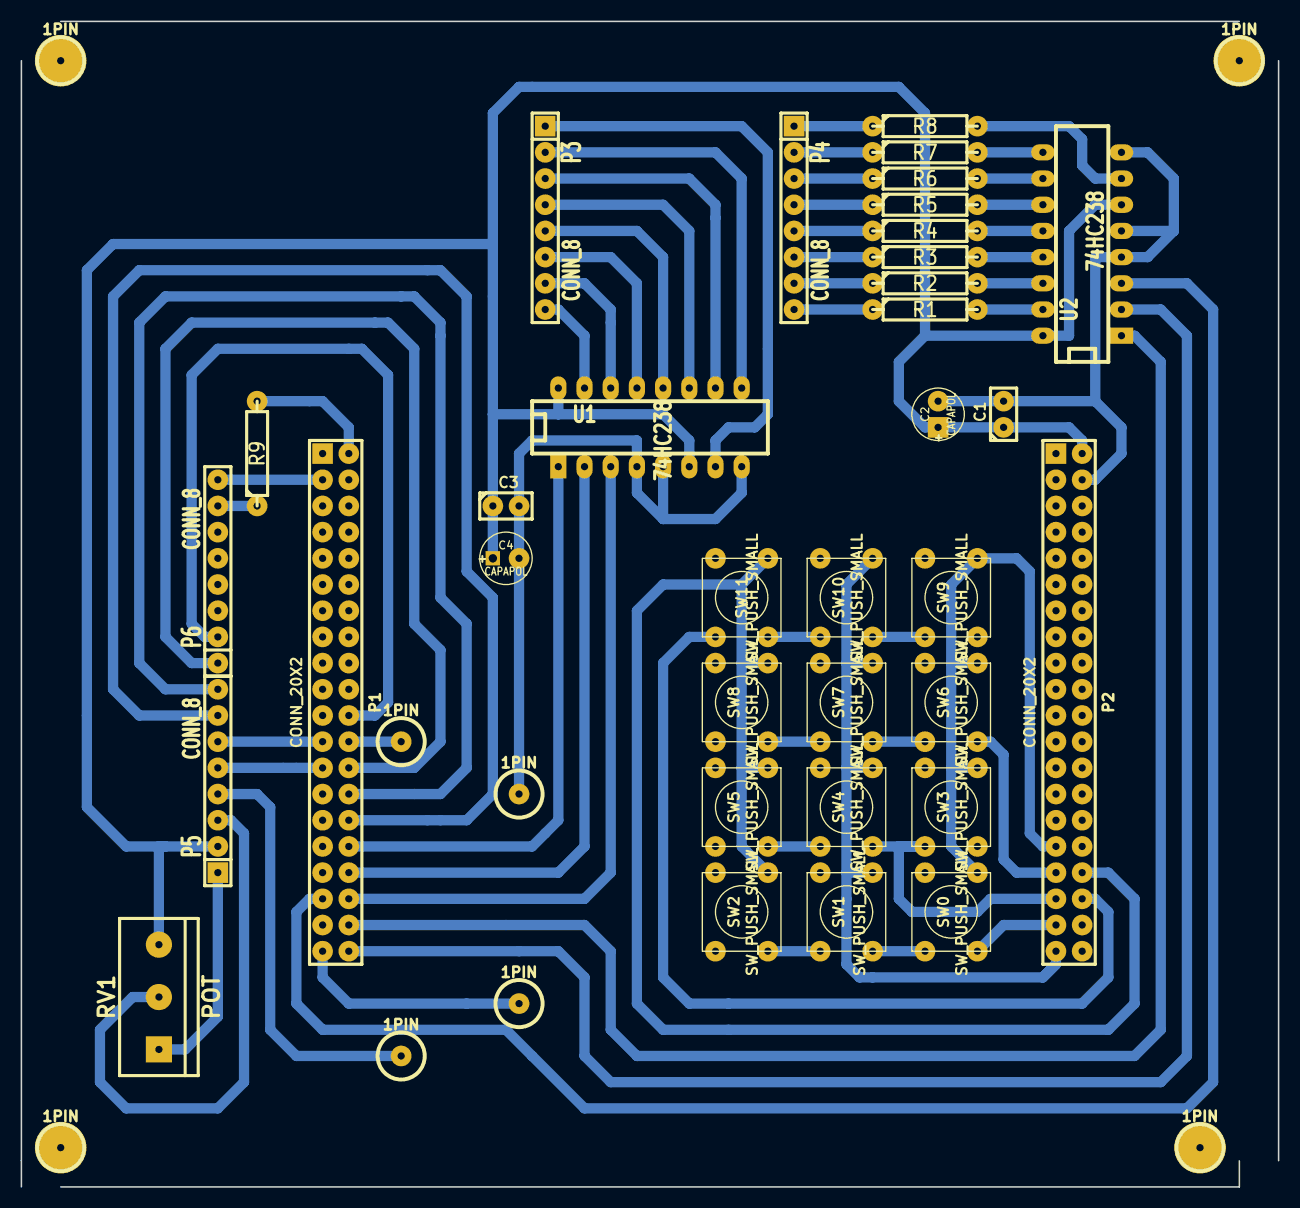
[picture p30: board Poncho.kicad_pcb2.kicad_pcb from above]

Board: 2 copper layers, 121.9 x 113.0 mm, 42 parts (0 on the bottom side), 50 nets.

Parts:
1PIN, 1PIN#2, 1PIN#3, 1PIN#4, 1PIN#5, 1PIN#6, 1PIN#7, 1PIN#8: P***; 1pin
C1, C3: C; C1
C2, C4: CAPAPOL; C1V5
P1, P2: CONN_20X2; PIN_ARRAY_20X2
P3, P4, P5, P6: CONN_8; SIL-8
R1, R2, R3, R4, R5, R6, R7, R8, R9: R; R4
RV1: POT; bornier3
SW0, SW1, SW2, SW3, SW4, SW5, SW6, SW7, SW8, SW9, SW10, SW11: SW_PUSH_SMALL; SW_PUSH_SMALL_I
U1, U2: 74HC238; DIP-16__300_ELL

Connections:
GND: 1PIN.1, 1PIN#2.1, 1PIN#3.1, 1PIN#4.1, C1.2, C2.2, C3.2, C4.2, P1.39, P2.4, U1.4, U1.5, U1.8, U2.4, U2.5, U2.8
unnamed: P6.7, R9.1
unnamed: P3.6, U1.13
unnamed: P3.5, U1.12
unnamed: P3.4, U1.11
unnamed: P3.3, U1.10
unnamed: P1.23, P5.6
unnamed: P3.1, U1.7
unnamed: P1.28, P5.8
unnamed: P1.34, U1.2
unnamed: P1.32, U1.1
unnamed: P1.36, U1.3
unnamed: P1.38, U2.1
unnamed: P1.35, U2.3
unnamed: P1.24, P5.4
unnamed: P1.22, P6.2
unnamed: P1.26, P6.1
unnamed: P1.30, P5.7
unnamed: P5.3, RV1.2
unnamed: P4.7, R2.1
unnamed: P3.2, U1.9
unnamed: P1.40, U2.2
unnamed: P1.3, P6.8
unnamed: P1.2, R9.2
unnamed: R7.2, U2.9
unnamed: P4.8, R1.1
unnamed: P4.6, R3.1
unnamed: P4.5, R4.1
unnamed: P4.4, R5.1
unnamed: P4.3, R6.1
unnamed: P4.2, R7.1
unnamed: P4.1, R8.1
unnamed: R8.2, U2.7
unnamed: R6.2, U2.10
unnamed: R5.2, U2.11
unnamed: R4.2, U2.12
unnamed: R3.2, U2.13
unnamed: R2.2, U2.14
unnamed: R1.2, U2.15
unnamed: P3.7, U1.14
unnamed: P3.8, U1.15
unnamed: P1.25, P5.1, P5.5, RV1.1
unnamed: P2.35, SW3.2, SW4.2, SW5.2
unnamed: P2.37, SW0.2, SW1.2, SW2.2
unnamed: P2.39, SW1.1, SW4.1, SW7.1, SW10.1
unnamed: P2.33, SW6.2, SW7.2, SW8.2
unnamed: P2.34, SW2.1, SW5.1, SW8.1, SW11.1
unnamed: P2.31, SW0.1, SW3.1, SW6.1, SW9.1
unnamed: P2.36, SW9.2, SW10.2, SW11.2
VCC: C1.1, C2.1, C3.1, C4.1, P2.2, P5.2, RV1.3, U1.6, U1.16, U2.6, U2.16

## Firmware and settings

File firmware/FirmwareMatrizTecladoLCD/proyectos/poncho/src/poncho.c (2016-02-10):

/* Copyright 2014, 2015 Mariano Cerdeiro
 * Copyright 2014, Pablo Ridolfi
 * Copyright 2014, Juan Cecconi
 * Copyright 2014, Gustavo Muro
 * All rights reserved.
 *
 * This file is part of CIAA Firmware.
 *
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
 * 3. Neither the name of the copyright holder nor the names of its
 *    contributors may be used to endorse or promote products derived from this
 *    software without specific prior written permission.
 *
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
 */

/** \brief Bare Metal example source file
 **
 ** This is a mini example of the CIAA Firmware.
 **
 **/

/** \addtogroup CIAA_Firmware CIAA Firmware
 ** @{ */
/** \addtogroup Examples CIAA Firmware Examples
 ** @{ */
/** \addtogroup Baremetal Bare Metal example source file
 ** @{ */

/*
 * Initials     Name
 * ---------------------------
 *
 *
 *
 */

/*
 * modification history (new versions first)
 * -----------------------------------------------------------
 * yyyymmdd v0.0.1 initials initial version
 */

/*==================[inclusions]=============================================*/
//#include "os.h"               /* <= operating system header */
//#include "ciaaPOSIX_stdio.h"  /* <= device handler header */
//#include "ciaaPOSIX_string.h" /* <= string header */
//#include "ciaak.h"            /* <= ciaa kernel header */
#include "poncho.h"       /* <= own header */
#include "letrasMatriz.h" //Contiene las constantes de todas las letras representadas en la matriz de leds

/*==================[macros and definitions]=================================*/
#define CPU lpc4337
#ifndef CPU
#error CPU shall be defined
#endif
#if (lpc4337 == CPU)
#include "chip.h"
#elif (mk60fx512vlq15 == CPU)
#else
#endif

#define defnum		3	//caracteres numeros
#define defAO		4	//caracteres letras mayusculas de A-O
#define defPZ		5	//caracteres letras mayusculas de P-Z
#define defao		6	//caracteres letras minusculas de a-o
#define defpz		7	//caracteres letras minusculas de p-z

#define letrasPorPalabra 2	//Tamaño maximo de palabra en la matriz (deberia ser 16 como minimo)
#define dimPalabraX (dimLetraX*letrasPorPalabra)+letrasPorPalabra
#define dimMatriz 8

#define dimTexto 16
#define cantFunc 3
#define cantOpciones 3

/*--------------------- Constantes de Funcion -------------------------*/
const char funciones[cantFunc][dimTexto] = {
		{"Escribir Texto  "},
		{"Enviar Texto    "},
		{"Velocidad Matriz"},
};

const char ModoEscritura[cantOpciones][dimTexto] = {
		{"Escribir Texto  "},
		{"Borrar Texto    "},
		{"Desea Salir?    "},
};

//"Escribir Texto  " escribe sobre el buffer de texto de la matriz
//"Enviar Texto    " refresca el texto de la matriz           <---------------- necesario?
//"Desplazar Texto " mueve el contenido de la matriz de izquierda a derecha rotativamente
//"Dibujo Continuo " moviendose con las flechitas dibuja en todo momento, excepto si se presiona la tecla 5.
//"Dibujo Pulsante " moviendose con las flechitas dibuja solo se dibuja si se presiona la tecla 5.

/*==================[internal data declaration]==============================*/

/*Variables globales*/
int x,y,fil,col;
int desp=150;
char despHab=0;

/*Variables de matriz*/
uint8_t matriz[dimLetraY][dimPalabraX];
uint8_t dibujo[dimMatriz][dimMatriz];

/*Variables de LCD*/
int posicion=0x00;
char Texto[dimTexto];
char c=' ';

/*Variables de Teclado*/
int caracteres=0;
char cambio=0;
long velMatriz=199999;
int velLCD;


/*==================[internal functions declaration]=========================*/

/*==================[internal data definition]===============================*/

/*==================[external data definition]===============================*/

/*==================[internal functions definition]==========================*/
void inicializarGPIO(void){
	/* Switches */
		Chip_SCU_PinMux(1,0,MD_PUP|MD_EZI|MD_ZI,FUNC0); /* GPIO0[4], SW1 */
		Chip_SCU_PinMux(1,1,MD_PUP|MD_EZI|MD_ZI,FUNC0); /* GPIO0[8], SW2 */
		Chip_SCU_PinMux(1,2,MD_PUP|MD_EZI|MD_ZI,FUNC0); /* GPIO0[9], SW3 */
		Chip_SCU_PinMux(1,6,MD_PUP|MD_EZI|MD_ZI,FUNC0); /* GPIO1[9], SW4 */

		Chip_GPIO_SetDir(LPC_GPIO_PORT, 0,(1<<4)|(1<<8)|(1<<9),0);
		Chip_GPIO_SetDir(LPC_GPIO_PORT, 1,(1<<9),0);
	/* LEDs */
		Chip_SCU_PinMux(2,0,MD_PUP|MD_EZI,FUNC4);  /* GPIO5[0], LED0R */
		Chip_SCU_PinMux(2,1,MD_PUP|MD_EZI,FUNC4);  /* GPIO5[1], LED0G */
		Chip_SCU_PinMux(2,2,MD_PUP|MD_EZI,FUNC4);  /* GPIO5[2], LED0B */
		Chip_SCU_PinMux(2,10,MD_PUP|MD_EZI,FUNC0); /* GPIO0[14], LED1 */
		Chip_SCU_PinMux(2,11,MD_PUP|MD_EZI,FUNC0); /* GPIO1[11], LED2 */
		Chip_SCU_PinMux(2,12,MD_PUP|MD_EZI,FUNC0); /* GPIO1[12], LED3 */

		Chip_GPIO_SetDir(LPC_GPIO_PORT, 5,(1<<0)|(1<<1)|(1<<2),1);
		Chip_GPIO_SetDir(LPC_GPIO_PORT, 0,(1<<14),1);
		Chip_GPIO_SetDir(LPC_GPIO_PORT, 1,(1<<11)|(1<<12),1);

		Chip_GPIO_ClearValue(LPC_GPIO_PORT, 5,(1<<0)|(1<<1)|(1<<2));
		Chip_GPIO_ClearValue(LPC_GPIO_PORT, 0,(1<<14));
		Chip_GPIO_ClearValue(LPC_GPIO_PORT, 1,(1<<11)|(1<<12));
	//----------------------------------------------------------------------
	//Matriz 8x8
	//PinMux
		Chip_SCU_PinMux(1,3,MD_PUP|MD_EZI,FUNC0);	/* GPIO0[10], SPI_SCK	*/
		Chip_SCU_PinMux(6,4,MD_PUP|MD_EZI,FUNC0);  /* GPIO3[3], GPIO1 */
		Chip_SCU_PinMux(6,7,MD_PUP|MD_EZI,FUNC4);  /* GPIO5[15], GPIO3 */
		Chip_SCU_PinMux(6,9,MD_PUP|MD_EZI,FUNC0);  /* GPIO3[5], GPIO5 */

		Chip_SCU_PinMux(6,8,MD_PUP|MD_EZI,FUNC4);	/*	GPIO5[16], GPIO04 */
		Chip_SCU_PinMux(6,10,MD_PUP|MD_EZI,FUNC0);  /* GPIO3[6], GPIO6 */
		Chip_SCU_PinMux(6,11,MD_PUP|MD_EZI,FUNC0);  /* GPIO3[7], GPIO7 */
		Chip_SCU_PinMux(6,12,MD_PUP|MD_EZI,FUNC0);  /* GPIO2[8], GPIO8 */

	//SetDir
		Chip_GPIO_SetDir(LPC_GPIO_PORT, 3,(1<<3)|(1<<5)|(1<<6)|(1<<7),1); //GPIO1;5;6;7
		Chip_GPIO_SetDir(LPC_GPIO_PORT, 5,(1<<15)|(1<<16),1); //GPIO3 y GPIO4
		Chip_GPIO_SetDir(LPC_GPIO_PORT, 2,(1<<8),1); //GPIO8
		Chip_GPIO_SetDir(LPC_GPIO_PORT, 0,(1<<10),1);//SPI_MISO

	//Teclado matricial de 4x3

	// PinMUX
		Chip_SCU_PinMux(4,0,MD_PUP|MD_EZI|MD_ZI,FUNC0);
		Chip_SCU_PinMux(4,1,MD_PUP|MD_EZI|MD_ZI,FUNC0);
		Chip_SCU_PinMux(4,2,MD_PUP|MD_EZI|MD_ZI,FUNC0);
		Chip_SCU_PinMux(4,3,MD_PUP|MD_EZI|MD_ZI,FUNC0);
		Chip_SCU_PinMux(1,5,MD_PUP|MD_EZI|MD_ZI,FUNC0);
		Chip_SCU_PinMux(7,4,MD_PUP|MD_EZI|MD_ZI,FUNC0);
		Chip_SCU_PinMux(7,5,MD_PUP|MD_EZI|MD_ZI,FUNC0);

	// SetDIR
		Chip_GPIO_SetDir(LPC_GPIO_PORT, 2, (1<<0)|(1<<1)|(1<<2)|(1<<3), 1); // T_FIL0-3
		Chip_GPIO_SetDir(LPC_GPIO_PORT, 1, (1<<8), 0); // T_COL0
		Chip_GPIO_SetDir(LPC_GPIO_PORT, 3, (1<<13), 0); // T_COL2
		Chip_GPIO_SetDir(LPC_GPIO_PORT, 3, (1<<12), 0); // T_COL1

	//----------------------------------------------------------------------------
	//LCD
	//PinMux
		Chip_SCU_PinMux(4,4,MD_PUP|MD_EZI,FUNC0);//LCD1
		Chip_SCU_PinMux(4,5,MD_PUP|MD_EZI,FUNC0);//LCD2
		Chip_SCU_PinMux(4,6,MD_PUP|MD_EZI,FUNC0);//LCD3
		Chip_SCU_PinMux(4,10,MD_PUP|MD_EZI,FUNC4);//LCD4
		Chip_SCU_PinMux(4,8,MD_PUP|MD_EZI,FUNC4);//LCD_RS
		Chip_SCU_PinMux(4,9,MD_PUP|MD_EZI,FUNC4);//LCD_EN
	//SetDir
		Chip_GPIO_SetDir(LPC_GPIO_PORT, 2, (1<<4)|(1<<5)|(1<<6), 1);//LCD1-3
		Chip_GPIO_SetDir(LPC_GPIO_PORT, 5, (1<<12)|(1<<13)|(1<<14), 1);//RS;EN;LCD4
	//Limpiar
		Chip_GPIO_ClearValue(LPC_GPIO_PORT,  5, (1<<12)|(1<<13)|(1<<14));
		Chip_GPIO_ClearValue(LPC_GPIO_PORT,  2, (1<<4)|(1<<5)|(1<<6));
}

void delay(int n){ //Retardo de 10 ms base
	long retardo;
	int m;
	for(m=0;m<n;m++){
		for( retardo=0;retardo<velMatriz;retardo++);
	}
}

void datosLCD(int valor){
	if((valor&0x01)==0x01){
		Chip_GPIO_SetValue(LPC_GPIO_PORT, 2, 1<<4);
	}else{
		Chip_GPIO_ClearValue(LPC_GPIO_PORT,  2, (1<<4));
	}
	if((valor&0x02)==0x02){
		Chip_GPIO_SetValue(LPC_GPIO_PORT, 2, 1<<5);
	}else{
		Chip_GPIO_ClearValue(LPC_GPIO_PORT,  2, (1<<5));
	}
	if((valor&0x04)==0x04){
		Chip_GPIO_SetValue(LPC_GPIO_PORT, 2, 1<<6);
	}else{
		Chip_GPIO_ClearValue(LPC_GPIO_PORT,  2, (1<<6));
	}
	if((valor&0x08)==0x08){
		Chip_GPIO_SetValue(LPC_GPIO_PORT, 5, 1<<14);
	}else{
		Chip_GPIO_ClearValue(LPC_GPIO_PORT,  5, (1<<14));
	}
	if((valor&0x10)==0x10){
		Chip_GPIO_SetValue(LPC_GPIO_PORT, 5, 1<<12);
	}else{
		Chip_GPIO_ClearValue(LPC_GPIO_PORT,  5, (1<<12));
	}
	if((valor&0x20)==0x20){
		Chip_GPIO_SetValue(LPC_GPIO_PORT, 5, 1<<13);
	}else{
		Chip_GPIO_ClearValue(LPC_GPIO_PORT,  5, (1<<13));
	}
}

void lcd_send(void){
	Chip_GPIO_SetValue(LPC_GPIO_PORT, 5, 1<<13);
	delay(1);
	Chip_GPIO_ClearValue(LPC_GPIO_PORT, 5, 1<<13);
}

void lcd_clear(void){
	datosLCD(0x00);
	lcd_send();
	datosLCD(0x01);
	lcd_send();
}

void lcd_init(void){
	delay(5);

	datosLCD(0x03); //Function set ( Interface is 8 bits long. )
	lcd_send();

	delay(5);

	datosLCD(0x02);	//Set interface data length [0 0 1 DL | N F － －]
	lcd_send();		//(DL:8-bit/4-bit), numbers of display line
	datosLCD(0x08);	//(N:2-line/1-line) and, display font type
	lcd_send();		//(F:5×11 dots/5×8 dots)

	delay(1);

	datosLCD(0x00);	//Display ON/OFF Control
	lcd_send();		//The number of display lines and character font can not be changed after this point.
	datosLCD(0x0F); //1|D|C|B - Sets On/Off of all display (D), cursor On/Off (C) and blink of cursor position character (B).
	lcd_send();

	delay(1);

	datosLCD(0x00);	//EntryMode	Set
	lcd_send();		//Assign cursor moving direction and enable the shift of entire display.
	datosLCD(0x06); //0 | 1 | I/D | SH --- (Increment / Decrement)
	lcd_send();

	delay(1);

	datosLCD(0x00); //Return Home
	datosLCD(0x02);
	lcd_send();

	delay(1);

	posicion=0x00;//indice inicializado
	lcd_clear();

}

void lcd_printchar(char C){
	switch(C){
		case 'A':
		case 'B':
		case 'C':
		case 'D':
		case 'E':
		case 'F':
		case 'G':
		case 'H':
		case 'I':
		case 'J':
		case 'K':
		case 'L':
		case 'M':
		case 'N':
		case 'O':
			datosLCD(defAO|0x10);
			lcd_send();
			C = C - 0x40;
			datosLCD(C|0x10);
			break;

		case 'P':
		case 'Q':
		case 'R':
		case 'S':
		case 'T':
		case 'U':
		case 'V':
		case 'W':
		case 'X':
		case 'Y':
		case 'Z':
			datosLCD(defPZ|0x10);
			lcd_send();
			C = C - 0x40;
			datosLCD(C|0x10);
			break;

		case 'a':
		case 'b':
		case 'c':
		case 'd':
		case 'e':
		case 'f':
		case 'g':
		case 'h':
		case 'i':
		case 'j':
		case 'k':
		case 'l':
		case 'm':
		case 'n':
		case 'o':
			datosLCD(defao|0x10);
			lcd_send();
			C = C - 0x60;
			datosLCD(C|0x10);
		break;

		case 'p':
		case 'q':
		case 'r':
		case 's':
		case 't':
		case 'u':
		case 'v':
		case 'w':
		case 'x':
		case 'y':
		case 'z':
			datosLCD(defpz|0x10);
			lcd_send();
			C = C - 0x60;
			datosLCD(C|0x10);
		break;

		case '0':
		case '1':
		case '2':
		case '3':
		case '4':
		case '5':
		case '6':
		case '7':
		case '8':
		case '9':
			datosLCD(defnum|0x10);
			lcd_send();
			C = C - 0x30;
			datosLCD(C|0x10);
		break;

		case ' ':
			datosLCD(0x18);
			lcd_send();
			datosLCD(0x18);
		break;

		case '.':
			datosLCD(0x12);
			lcd_send();
			datosLCD(0x1E);

		break;

		case ',':
			datosLCD(0x12);
			lcd_send();
			datosLCD(0x1C);
		break;

		case '(':
			datosLCD(0x12);
			lcd_send();
			datosLCD(0x18);
		break;

		case ')':
			datosLCD(0x12);
			lcd_send();
			datosLCD(0x19);

		break;

		case '*':
			datosLCD(0x12);
			lcd_send();
			datosLCD(0x1A);
		break;

		case '+':
			datosLCD(0x12);
			lcd_send();
			datosLCD(0x1B);

		break;

		case '-':
			datosLCD(0x12);
			lcd_send();
			datosLCD(0x1D);
		break;

		case '/':
			datosLCD(0x12);
			lcd_send();
			datosLCD(0x1F);

		break;

		case '!':
			datosLCD(0x12);
			lcd_send();
			datosLCD(0x11);
		break;

		case '#':
			datosLCD(0x12);
			lcd_send();
			datosLCD(0x13);
		break;

		case '$':
			datosLCD(0x12);
			lcd_send();
			datosLCD(0x14);

		break;

		case '&':
			datosLCD(0x12);
			lcd_send();
			datosLCD(0x16);
		break;

		case '\'':
		case '"':
			datosLCD(0x12);
			lcd_send();
			datosLCD(0x17);
		break;

		case '%':
			datosLCD(0x12);
			lcd_send();
			datosLCD(0x15);
		break;

		case ':':
			datosLCD(0x13);
			lcd_send();
			datosLCD(0x1A);
		break;

		case ';':
			datosLCD(0x13);
			lcd_send();
			datosLCD(0x1B);
		break;

		case '<':
			datosLCD(0x13);
			lcd_send();
			datosLCD(0x1C);
		break;

		case '=':
			datosLCD(0x13);
			lcd_send();
			datosLCD(0x1D);
		break;

		case '>':
			datosLCD(0x13);
			lcd_send();
			datosLCD(0x1E);
		break;

		case '?':
			datosLCD(0x13);
			lcd_send();
			datosLCD(0x1F);
		break;

		case '_':
			datosLCD(0x15);
			lcd_send();
			datosLCD(0x1F);
		break;
		default:
			//no hace nada
			break;
	}
	lcd_send();
}

void lcd_cursor(uint8_t ddramAddress) {
    int ddaux = ddramAddress >> 4;
    ddaux |= 0x08;
    ddaux = ddaux & 0x0F;

    datosLCD(ddaux);
	lcd_send();

	ddaux = ddramAddress & 0x0F;
	datosLCD(ddaux);
	lcd_send();
}

void lcd_L1(void) {
	posicion=0x00;
	lcd_cursor(posicion);
}

void lcd_L2(void) {
	posicion=0x40;
	lcd_cursor(posicion);

}

void lcd_imprimir8(const char* s){
	int i;
	for(i=0; i<8;i++){
		lcd_printchar(s[i]);
		posicion++;
	}
}

void lcd_imprimir16(const char* s){
	int i;
	for(i=0; i<16;i++){
		lcd_printchar(s[i]);
		posicion++;
	}
}

void lcd_imprimir32(char* s){
	int i;
	lcd_L1();
	for(i=0; i<16;i++){
		lcd_printchar(s[i]);
		posicion++;
	}

	lcd_L2();
	for(i=16; i<32;i++){
		lcd_printchar(s[i]);
		posicion++;
	}
}

void datosLEDs(int valor){
	if((valor&0x01)==0x01){
		Chip_GPIO_SetValue(LPC_GPIO_PORT, 5, 1<<0);
	}else{
		Chip_GPIO_ClearValue(LPC_GPIO_PORT,  5, (1<<0));
	}
	if((valor&0x02)==0x02){
		Chip_GPIO_SetValue(LPC_GPIO_PORT, 5, 1<<1);
	}else{
		Chip_GPIO_ClearValue(LPC_GPIO_PORT,  5, (1<<1));
	}
	if((valor&0x04)==0x04){
		Chip_GPIO_SetValue(LPC_GPIO_PORT, 5, 1<<2);
	}else{
		Chip_GPIO_ClearValue(LPC_GPIO_PORT,  5, (1<<2));
	}
	if((valor&0x08)==0x08){
		Chip_GPIO_SetValue(LPC_GPIO_PORT, 0, 1<<14);
	}else{
		Chip_GPIO_ClearValue(LPC_GPIO_PORT,  0, (1<<14));
	}
	if((valor&0x10)==0x10){
		Chip_GPIO_SetValue(LPC_GPIO_PORT, 1, 1<<11);
	}else{
		Chip_GPIO_ClearValue(LPC_GPIO_PORT,  1, (1<<11));
	}
	if((valor&0x20)==0x20){
		Chip_GPIO_SetValue(LPC_GPIO_PORT, 1, 1<<12);
	}else{
		Chip_GPIO_ClearValue(LPC_GPIO_PORT,  1, (1<<12));
	}
}

void salidasTECLADO(int valor){
	if((valor&0x01)==0x01){
		Chip_GPIO_SetValue(LPC_GPIO_PORT, 2, 1<<0);
	}else{
		Chip_GPIO_ClearValue(LPC_GPIO_PORT,  2, (1<<0));
	}
	if((valor&0x02)==0x02){
		Chip_GPIO_SetValue(LPC_GPIO_PORT, 2, 1<<1);
	}else{
		Chip_GPIO_ClearValue(LPC_GPIO_PORT,  2, (1<<1));
	}
	if((valor&0x04)==0x04){
		Chip_GPIO_SetValue(LPC_GPIO_PORT, 2, 1<<2);
	}else{
		Chip_GPIO_ClearValue(LPC_GPIO_PORT,  2, (1<<2));
	}
	if((valor&0x08)==0x08){
		Chip_GPIO_SetValue(LPC_GPIO_PORT, 2, 1<<3);
	}else{
		Chip_GPIO_ClearValue(LPC_GPIO_PORT,  2, (1<<3));
	}
}

int entradasTECLADO(void){//lectura fisica de los datos del teclado
	int valorR=0;
	if((Chip_GPIO_ReadValue(LPC_GPIO_PORT,3)&(1<<13))==0){//Columna 1
		valorR += 0x01;
	}
	if((Chip_GPIO_ReadValue(LPC_GPIO_PORT,1)&(1<<8))==0){//Columna 2
		valorR += 0x02;
	}
	if((Chip_GPIO_ReadValue(LPC_GPIO_PORT,3)&(1<<12))==0){//Columna 3
		valorR += 0x04;
	}
	return valorR;
}

int leerTeclado(void){//interpretación por software de los datos del teclado
	int valor=0;
	int tecla=0;
	switch (fil){
	case 0:
		salidasTECLADO(0x0D); //Fila 1
		tecla=entradasTECLADO();
		if(tecla==1){
			valor = 1;
		}
		if(tecla==2){
			valor = 2;
		}
		if(tecla==4){
			valor = 3;
		}
		break;
	case 1:
		salidasTECLADO(0x07);//Fila 2
		tecla=entradasTECLADO();
		if(tecla==1){
			valor = 4;
		}
		if(tecla==2){
			valor = 5;
		}
		if(tecla==4){
			valor = 6;
		}
		break;
	case 2:
		salidasTECLADO(0x0B);
		tecla=entradasTECLADO();
		if(tecla==1){
			valor = 7;
		}
		if(tecla==2){
			valor = 8;
		}
		if(tecla==4){
			valor = 9;
		}
		break;
	case 3:
		salidasTECLADO(0x0E);
		tecla=entradasTECLADO();
		if(tecla==1){
			valor = 10;
		}
		if(tecla==2){

			valor = 11;
		}
		if(tecla==4){
			valor = 12;
		}
		break;
	case 4:
		fil=-1;
		break;
	default:
		break;
	}
	fil++;
	return valor;
}

void escribirLCD(int posicion){
	char funcionActiva=1;
	char contador=0;
	int boton=0;
	int tecla = leerTeclado();
	cambio=0;

	for(caracteres=0;caracteres<dimTexto;caracteres++){//Reinicializa el texto
		Texto[caracteres]=' ';
	}
	caracteres=0;

	while(funcionActiva){
		lcd_cursor(posicion);
		while(!tecla){
			tecla = leerTeclado();
		}
		switch(leerTeclado()){
			case 1://funcion 1: simbolos-1
				if(boton!=1){
					contador=0;
					boton=1;
				}
				if(contador < 15){
					c=('!'+contador);
					contador++;
				}
				else{
					c='1';
					contador=0;
				}
				lcd_printchar(c);
				break;

			case 2://funcion 2: a-b-c-A-B-C-2
				if(boton!=2){
					contador=0;
					boton=2;
				}
				if(contador < 6){
					if(contador < 3){
						c=('a'+contador);
					}
					else{
						c=('A'+contador-3);
					}
					contador++;
				}
				else{
					c=('2');
					contador=0;
				}
				lcd_printchar(c);
				break;

			case 3://funcion 3: d-e-f-D-E-F-3
				if(boton!=3){
					contador=0;
					boton=3;
				}
				if(contador < 6){
					if(contador < 3){
						c=('d'+contador);
					}
					else{
						c=('D'+contador-3);
					}
					contador++;
				}
				else{
					c=('3');
					contador=0;
				}
				lcd_printchar(c);
				break;

			case 4://funcion 7: p-q-r-s-P-Q-R-S-7
				if(boton!=4){
					contador=0;
					boton=4;
				}
				if(contador < 8){
					if(contador < 4){
						c=('p'+contador);
					}
					else{
						c=('P'+contador-4);
					}
					contador++;
				}
				else{
					c=('7');
					contador=0;
				}
				lcd_printchar(c);
				break;

			case 5://funcion 8: t-u-v-w-T-U-V-W-8
				if(boton!=5){
					contador=0;
					boton=5;
				}
				if(contador < 8){
					if(contador < 4){
						c=('t'+contador);
					}
					else{
						c=('T'+contador-4);
					}
					contador++;
				}
				else{
					c=('8');
					contador=0;
				}
				lcd_printchar(c);
				break;

			case 6://funcion 9: x-y-z-X-Y-Z-9
				if(boton!=6){
					contador=0;
					boton=6;
				}
				if(contador < 6){
					if(contador < 3){
						c=('x'+contador);
					}
					else{
						c=('X'+contador-3);
					}
					contador++;
				}
				else{
					c=('9');
					contador=0;
				}
				lcd_printchar(c);
				break;

			case 7://funcion 4: g-h-i-G-H-I-4
				if(boton!=7){
					contador=0;
					boton=7;
				}
				if(contador < 6){
					if(contador < 3){
						c=('g'+contador);
					}
					else{
						c=('G'+contador-3);
					}
					contador++;
				}
				else{
					c=('4');
					contador=0;
				}
				lcd_printchar(c);
				break;

			case 8://funcion 5: j-k-l-J-K-L-5
				if(boton!=8){
					contador=0;
					boton=8;
				}
				if(contador < 6){
					if(contador < 3){
						c=('j'+contador);
					}
					else{
						c=('J'+contador-3);
					}
					contador++;
				}
				else{
					c=('5');
					contador=0;
				}
				lcd_printchar(c);
				break;

			case 9://funcion 6: m-n-o-M-N-O-6
				if(boton!=9){
					contador=0;
					boton=9;
				}
				if(contador < 6){
					if(contador < 3){
						c=('m'+contador);
					}
					else{
						c=('M'+contador-3);
					}
					contador++;
				}
				else{
					c=('6');
					contador=0;
				}
				lcd_printchar(c);
				break;

			case 10://funcion 10: BOTON ACEPTAR
				if(boton!=10){
					contador=0;
					boton=10;
				}
				if(cambio==2){//si antes se presiono ESCAPE, sale de la funcion escribir
					funcionActiva=0;
				}
				else{//escribe caracter
					if(cambio!=0){
						lcd_L1();
						lcd_imprimir16(ModoEscritura[0]);
						cambio=0;
						lcd_cursor(posicion);
					}
					if(c!='\0'){
						Texto[caracteres]= c;
						if(caracteres<dimTexto){
							posicion++;
							caracteres++;
						}
						c='\0';
					}
				}
				break;

			case 11://funcion 11: espacio-simbolos-0
				if(boton!=11){
					contador=0;
					boton=11;
				}
				if(contador<6){
					if(contador==0){
						c=(' ');
						contador++;
					}
					else{
						c=('0'+9+contador);
						contador++;
					}
				}
				else{
					c=('0');
					contador=0;
				}
				lcd_printchar(c);
				break;

			case 12://funcion 12: BOTON ESCAPE
				if(boton!=12){
					if(cambio!=2){
						lcd_L1();
						lcd_imprimir16(ModoEscritura[2]);
						lcd_cursor(posicion);
						cambio=2;
					}
					boton=12;
					contador=0;
				}
				else{
					if(caracteres > 0){
						if(cambio!=1){
							lcd_L1();
							lcd_imprimir16(ModoEscritura[1]);
							cambio=1;
						}

						if(posicion>0){
							lcd_cursor(posicion-1);
							lcd_printchar(' ');
							posicion--;
							caracteres--;
						}
						else{
							lcd_printchar(' ');
							posicion=0;
							caracteres=0;
						}
					}
					else{
						if(cambio == 2){
							lcd_L1();
							lcd_imprimir16(ModoEscritura[0]);
							cambio=0;
							lcd_cursor(posicion);
						}
						else{
							lcd_L1();
							lcd_imprimir16(ModoEscritura[2]);
							lcd_cursor(posicion);
							cambio=2;
						}
					}
				}
				break;

			default:
				//No hace nada - Ninguna tecla presionada
				break;
		}
	}
}
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
int main(void){
   //Inicializar Variables
    int pos;
    int indiceMenu;
	/* perform the needed initialization here */
	inicializarGPIO();

	datosMATRIZ(0x08);//la matriz de leds inicia apagada
	//datosLEDs(0x10); //Prender Led Rojo	lcd_init();
	lcd_init();

	lcd_imprimir16("** Bienvenido **");
	lcd_L2();
	lcd_imprimir16(" Elegir Funcion ");
	delay(120);
	while(1){
		//Imprime titulo
		lcd_clear();
		lcd_L1();
		lcd_imprimir16("  *** Menu ***  ");

		//Selección de función
		indiceMenu=elegirFuncion();

		//Imprime nombre de función
		lcd_clear();
		lcd_L1();
		lcd_imprimir16(funciones[indiceMenu]);
		lcd_L2();

		//Inicializa las variables y habilita las funciones
		switch(indiceMenu){
			case 0:
				//Escribir texto
				pos= posicion;
				escribirLCD(pos);
				break;
			case 1:
				enviaTexto();
				break;
			case 2:
				velocidadDespMatriz();
				break;
			default:
				//no hace nada
				break;
		}
	}
	return 0;
}


/** @} doxygen end group definition */
/** @} doxygen end group definition */
/** @} doxygen end group definition */
/*==================[end of file]============================================*/

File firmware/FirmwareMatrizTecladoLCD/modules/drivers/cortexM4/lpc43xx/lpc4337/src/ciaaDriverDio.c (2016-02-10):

/* Copyright 2014, 2015 Pablo Ridolfi (UTN-FRBA)
 * All rights reserved.
 *
 * This file is part of CIAA Firmware.
 *
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
 * 3. Neither the name of the copyright holder nor the names of its
 *    contributors may be used to endorse or promote products derived from this
 *    software without specific prior written permission.
 *
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
 */

/** \brief CIAA Dio Driver for LPC4337
 **
 ** Implements the Digital Input/Output (Dio) Driver for LPC4337
 **
 **/

/** \addtogroup CIAA_Firmware CIAA Firmware
 ** @{ */
/** \addtogroup Drivers CIAA Drivers
 ** @{ */
/** \addtogroup DIO DIO Drivers
 ** @{ */

/*
 * Initials     Name
 * ---------------------------
 * PR           Pablo Ridolfi
 */

/*
 * modification history (new versions first)
 * -----------------------------------------------------------
 * 20150831 v0.0.2   PR improved version
 * 20140731 v0.0.1   PR first functional version
 */

/*==================[inclusions]=============================================*/
#include "ciaaDriverDio.h"
#include "ciaaDriverDio_Internal.h"
#include "ciaaPOSIX_stdlib.h"
#include "ciaaPOSIX_string.h"
#include "chip.h"

/*==================[macros and definitions]=================================*/

/** \brief Managed input count */
#define ciaaDriverDio_InputCount (sizeof(ciaaDriverDio_Inputs) / sizeof(ciaaDriverDio_dioType))

/** \brief Managed output count */
#define ciaaDriverDio_OutputCount (sizeof(ciaaDriverDio_Outputs) / sizeof(ciaaDriverDio_dioType))

/** \brief Pointer to Devices */
typedef struct  {
   ciaaDevices_deviceType * const * const devices;
   uint8_t countOfDevices;
} ciaaDriverConstType;

/*==================[internal data declaration]==============================*/

/*==================[internal functions declaration]=========================*/

/*==================[internal data definition]===============================*/

/** \brief PORT/PIN map for managed GPIOs
 *
 * Define port/pin pairs for each GPIO managed by this driver
 */
#if (ciaa_nxp == BOARD)
const ciaaDriverDio_dioType ciaaDriverDio_Inputs[] = { {2,0},{2,1},{2,2},{2,3},{3,11},{3,12},{3,13},{3,14} };
const ciaaDriverDio_dioType ciaaDriverDio_Outputs[] =  { {5,1},{2,6},{2,5},{2,4},{5,12},{5,13},{5,14},{1,8} };
#elif (edu_ciaa_nxp == BOARD)
//const ciaaDriverDio_dioType ciaaDriverDio_Inputs[] = { {1,8},{3,12},{3,13} };//Cols Tec
//const ciaaDriverDio_dioType ciaaDriverDio_Outputs[] =  { {2,0},{2,1},{2,2},{2,3},{5,0},{5,1},{5,2}, {0,14} };//Primeros 4 Filas Tec, desp 3 led rgb
//const ciaaDriverDio_dioType ciaaDriverDio_Outputs[] =  { {2,4},{2,5},{2,6},{5,14},{5,12},{5,13}};//Pantalla LCD 1-4;RS;EN
const ciaaDriverDio_dioType ciaaDriverDio_Outputs[] =  { {3,3},{5,15},{3,5},{0,10},{3,7},{2,8},{3,6},{5,16} };//Gpios Demux Matrix
const ciaaDriverDio_dioType ciaaDriverDio_Inputs[] = { {0,4},{0,8},{0,9},{1,9} }; //Originales
//const ciaaDriverDio_dioType ciaaDriverDio_Outputs[] =  { {5,0},{5,1},{5,2},{0,14},{1,11},{1,12} };//Originales
#endif

/** \brief Device for DIO 0 */
static ciaaDevices_deviceType ciaaDriverDio_in0 = {
   "in/0",                          /** <= driver name */
   ciaaDriverDio_open,             /** <= open function */
   ciaaDriverDio_close,            /** <= close function */
   ciaaDriverDio_read,             /** <= read function */
   ciaaDriverDio_write,            /** <= write function */
   ciaaDriverDio_ioctl,            /** <= ioctl function */
   NULL,                           /** <= seek function is not provided */
   NULL,                           /** <= upper layer */
   NULL,                           /** <= layer */
   NULL                            /** <= NULL no lower layer */
};

/** \brief Device for DIO 1 */
static ciaaDevices_deviceType ciaaDriverDio_out0 = {
   "out/0",                          /** <= driver name */
   ciaaDriverDio_open,             /** <= open function */
   ciaaDriverDio_close,            /** <= close function */
   ciaaDriverDio_read,             /** <= read function */
   ciaaDriverDio_write,            /** <= write function */
   ciaaDriverDio_ioctl,            /** <= ioctl function */
   NULL,                           /** <= seek function is not provided */
   NULL,                           /** <= upper layer */
   NULL,                           /** <= layer */
   NULL                            /** <= NULL no lower layer */
};

static ciaaDevices_deviceType * const ciaaDioDevices[] = {
   &ciaaDriverDio_in0,
   &ciaaDriverDio_out0
};

static ciaaDriverConstType const ciaaDriverDioConst = {
   ciaaDioDevices,
   2
};

/*==================[external data definition]===============================*/

/*==================[internal functions definition]==========================*/

/** \brief perform low level gpio initialization for LPC4337
 */
static void ciaa_lpc4337_gpio_init(void)
{
   Chip_GPIO_Init(LPC_GPIO_PORT);
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

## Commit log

2016-02-11 Agregadas imagenes del poncho para la documentación.
2016-02-12 actualización de diapositivas
2016-02-20 Actualización de Esquematicos
    [Adaptador.sch, Poncho.sch]
